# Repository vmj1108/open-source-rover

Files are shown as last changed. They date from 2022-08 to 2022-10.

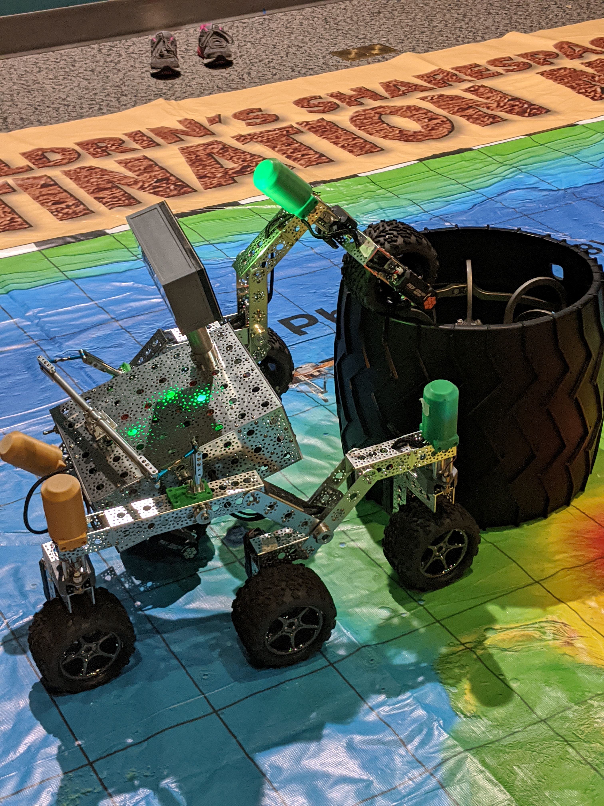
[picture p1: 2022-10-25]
examples/images/roverto/roverto_climbing_wheel.jpg

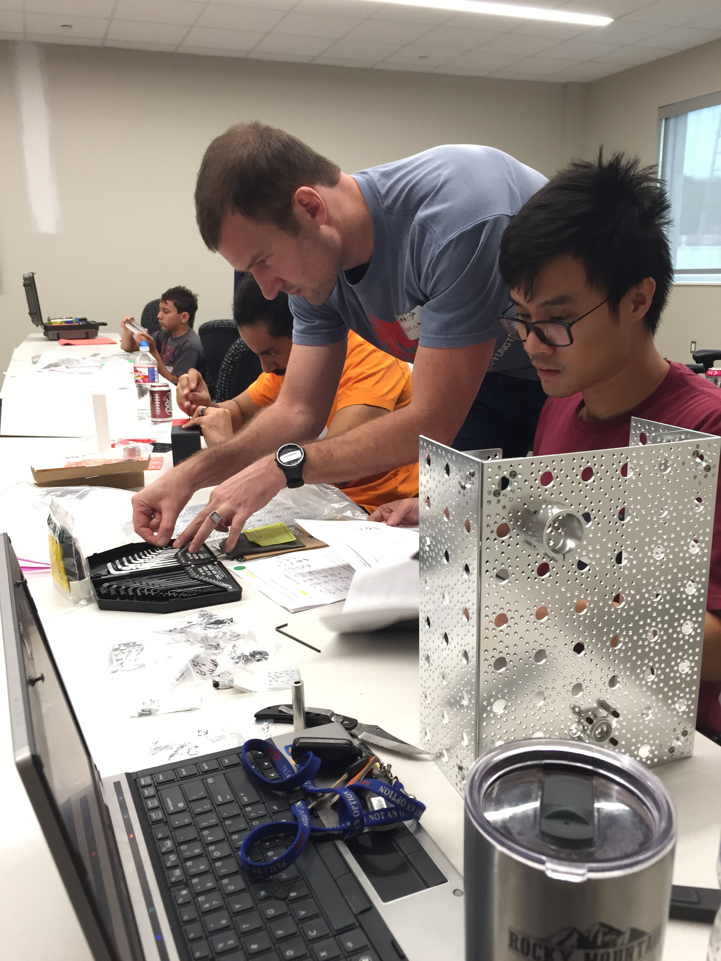
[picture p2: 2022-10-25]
examples/images/AUDACITY/IMG_3927.JPG

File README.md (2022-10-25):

# JPL Open Source Rover Project

The JPL Open Source Rover is an open source, build it yourself, scaled down version of the 6 wheel rover design that JPL uses to explore the surface of Mars. The Open Source Rover is designed almost entirely out of consumer off the shelf (COTS) parts. This project is intended to be a teaching and learning experience for those who want to get involved in mechanical engineering, software, electronics, or robotics.

<table>
 <tr>
  <td align="center" >  </td>
  <td align="center" > <a href="https://github.com/lschooley/open-source-rover-mission-patch">
    </a>
  </td>
 </tr>
 <tr>
  <td align="center" > </td>
 <td align="center" ></td>
 </tr>
</table>

A gallery of some community builds can be found [here](examples/builders_gallery.md).

## About the Project

### Motivation

JPL is always looking to inspire the next generation of scientists, engineers, and roboticists to help us explore and learn about our solar system (and beyond!). We release the plans for this rover as a way to try and give budding enthusiasts a fun robotics project that will help teach them and get them involved in robotics sooner and at a lower cost.

---

### Specifications & Technical Attributes

The specific attributes of the robot you build will depend slightly on the type of electronics and motors you buy for the system.  The numbers shown below are for the version of the robot that contains exactly the parts that we suggest in our build documents and parts list. Below, you can see which parts could be changed for which spec upgrades.

| Attribute | Value [imperial] | Value [SI] |
| --- |:-----: | :---: |
| Weight | 28 [lbs] | 12.7 [kg] |
| Footprint | 24x14 [in] | 60.96x30.48 [cm] |
| Battery Capacity | 5200 [mAh] | 5200 [mAh] |
| Battery Discharge Rate | 8 [A] | 8 [A] |
| Nominal Current Draw | 1.2 [A] | 1.2 [A] |
| Operating time | 5 [hrs] (continual use)  | 5 [hrs] (continual use)|
| Approximate Max speed | 68.8 [in/s] | 1.75 [m/s] |
| Maximum 90 deg vertical scale | 12 [in] | 30.48 [cm] |
| Maximum height differential between sides | 14 [in] | 35.56 [cm] |
| Communication (in this guide) | Bluetooth app (Android only) and Xbox Controller| |
| Cost (*) | ~ $2,500 | |

Again, the above statistics depend on which components you select when buying parts. One potential change is for the motors; you can, for example, select higher RPM motors (to drive your rover faster) at the sacrifice of max stall torque, which would potentially limit your rover's ability to climb. A selection of motors that would integrate easily with the rest of the suggested rover design can be found at [GoBilda](https://www.gobilda.com/5202-series-yellow-jacket-planetary-gear-motors/).

(*) Other open-source, cheaper alternatives exist but are slower, less strong, and are more fragile. See [Additional Projects](#additional-projects).

---

### Communication

In addition to this repository which holds all the documentation for this project, there are two additional websites tied to this project. One is a [landing site](https://opensourcerover.jpl.nasa.gov) which holds general information and an overview of the rover and how it works:

We have a few ways to connect with the team and community of Open Source Rover builders:

* [Slack](https://join.slack.com/t/opensourcerover/shared_invite/zt-mfe0viua-FhcYsNb3S9vUra99uF3IBw) (Preferred method)
* [TapaTalk - JPL Open Source Rover](https://www.tapatalk.com/groups/jpl_opensource_rover/) (Tapatalk is being monitored less since the addition of Slack, that's the easiest way to reach many of us now)
* We also use [Github Discussions](https://github.com/nasa-jpl/open-source-rover/discussions)

****Note: JPL and Caltech have no official affiliation with this forum; it is run by individuals of the general public.**** On these you can ask questions if you need help or clarification on any aspects of the project.  Additionally, you can post and promote any modifications or addons that you have created on this project. We highly encourage additions and modifications to be posted so that this project and community can grow.

---

### Features

This rover is designed to function similarly to the 6 wheel rover designs on Mars and employs a few of the major driving mechanics that the mars rovers use to traverse rocky surfaces:

* **Rocker-Bogie:** The Rocker-Bogie suspension system allows all 6 wheels to continually be in contact with the ground while climbing over obstacles
* **Differential Pivot:** Allows weight to be mechanically offloaded from one side of the rover to the other while climbing
* **6-Wheel Ackerman Steering:** Driving and steering/turning mechanism that governs where the wheels point and how fast each of them will move.

We chose a Raspberry Pi to be the "brain" of this rover for its versatility, accessibility, simplicity, and ability to add and upgrade your own modifications. Any method with which you can communicate with a Raspberry Pi (bluetooth, WiFi, USB devices, etc) can be interfaced into the control system of the robot.

Rover communication

In addition, here are the open communication ports and hardware on the Raspberry Pi:

* 4 USB ports (3 if using Xbox controller)
* RPi Camera port
* 1 I2C Bus (0 if using LED Matrix screen)
* 2 SPI Bus (1 if using LED Matrix screen)
* 3.5mm Audio Jack
* 13 GPIO pins (6 if using LED Matrix screen)

Using the above ports, you could theoretically drive the rover autonomously from the camera, via a USB dongle attached to anything (your own video game controller, a USB microphone, or many others... be creative!), or through any interface using the Pi's GPIO ports (distance sensors, accelerometers, and much more).  We've only given you two simple ways to control the rover to start... we want you to come up with even more!

For the power system of the rover, there is also ample spare power which can be used for your own addons and upgrades.  See the [Electrical subsystem documentation](electrical/) for more specific details.

---

### Maintenance Status

As an open-source hardware project, the rover is continuously improving. Please check ongoing [projects](https://github.com/nasa-jpl/open-source-rover/projects), [issues](https://github.com/nasa-jpl/open-source-rover/issues), [pull requests](https://github.com/nasa-jpl/open-source-rover/projects), and the forum (see below) to see if any big changes are expected soon.

### Online 3D Model


<p>

</p>

There is also an [Onshape model of the Open Source Rover](https://cad.onshape.com/documents/5c358484057fc4c01d5e5803/w/bdf583acdf29d75695be5fbc/e/e3eb7193ecdec5b0a710978b). The model includes the state of the rover at each individual step throughout our build instructions! Therefore, you should be able to reference the online 3D model in addition to the photos in the build instructions as you are building to ensure your build is going well. NOTE: The most updated model and single source of truth are the SolidWorks assemblies and the OnShape model may be out of date.

---

### Rover Mission Patch



Thank you to Lauren Schooley for creating a mission patch for the project. The patch is free for use as a team patch, for stickers, or decorating your rover. The design is released under the Creative Commons Attribution-NoDerivatives public license. A variety of file formats is available.

* [Mission Patch](https://github.com/lschooley/open-source-rover-mission-patch)

---

### Skills Necessary

This project has elements in mechanical assembly/fabrication, uses a host of electrical components, and has software that will run it all. In order to complete this project, you will need to have some experience in the following:

* **Fabrication/Machining:** Although most the parts are COTS there are a few modifications necessary to adapt them to the project. These modifications will be in the form of
  * Metal cutting using band saw/dremel
  * Drilling using drill press/hand drill
  * Filing and sanding for part cleanup
  * General Fabrication/Machining Safety
* **Electronics:** This project uses components like motors, motor controllers, and batteries. It will be important to have experience with the following electrical processes.
  * Soldering
  * Electrical debugging
  * Wiring
  * Electrical Safety
* **Software:** The rover's brain is a Raspberry Pi. All code can be found in the [osr-rover-code](https://github.com/nasa-jpl/osr-rover-code) repository along with step-by-step instructions to set it up. Basic familiarity with Linux, ROS, and Python will be helpful though.

Most of the above are skills that you can learn and pick up fairly quickly from watching videos and doing research on the internet, and throughout the project we try to give supplemental information on some of these as well.  See the build documents for more information.

---

### Tools Necessary

This project assumes you have some standard tools to help assemble the project. If you do not have any of the optional tools, we provide examples of online services that you can use to have the parts fabricated and sent to you.

#### Mandatory tools

* SAE Hex Key set
* SAE Wrench set
* Pliers
* Wire Snips
* Wire Strippers
* Solder Iron
* Solder
* Digital Multimeter
* Hand Drill or Drill Press
* Dremel, Band saw, or hand saw
* Items for operating a Raspberry Pi (Keyboard, mouse, monitor, 5V micro USB power adapter)
* Wire strippers, e.g. [these](https://www.amazon.com/dp/B07DWVSR41/?coliid=ISMG8XMBILGFK&colid=1IM7RHK25RIBB&psc=0&ref_=lv_vv_lig_dp_it)

#### Optional Tools

* 3D printer
* Laser Cutter
* Power Supply (to test without using battery)

---

### Expected time commitment

In our experience, this project takes no less than 200 person-hours to build, and depending on the familiarity and skill level of those involved could be significantly more. Experienced builders may be able to build this project in this amount of time.  However, this project is generally meant to be a teaching and learning tool.  Throughout the documentation, we try to give supplemental information for those who might be new to this kind of project.

# Disclaimer

**Reference herein to any specific commercial product, process, or service by trade name, trademark, manufacturer, or otherwise, does not constitute or imply its endorsement by the United States Government or the Jet Propulsion Laboratory, California Institute of Technology. Government sponsorship acknowledged.**

**By downloading, cloning, or otherwise using the contents of this repository, you agree to the terms specified in the attached [DISCLAIMER.txt file](/DISCLAIMER.txt).**

## Getting Started

---

### Ordering parts

#### Parts Lists

The [Master Parts List](parts_list/master_parts_list_raw.csv) contains all the parts necessary to build the entirety of the robot as it is listed in our documentation. We recognize that you may want to change, add, and redesign some sections, so each of the individual build sections also contain a parts list for that corresponding section of the project. *Note that these individual parts list recommend buying quantities necessary **only for that section**.  Be sure to assess the quantities you need for common items (particularly screws, nuts, bolts, and other common hardware) if you are changing subassemblies.*

##### Cart Share

In order to help this ordering process we have compiled a few links of a large number of these together already, if you wish to build exactly what is in our build documentation. Note that some of these parts might not be available or outdated. Please check the master parts list for the most up-to-date list of items.

|[McMaster](https://www.mcmaster.com/order/rcvRtedOrd.aspx?ordid=5887891246&lnktyp=txt)|[Amazon](https://www.amazon.com/gp/registry/wishlist/3ELV1FY8J7ZYP/ref=cm_sw_em_r_z_g__wb)|[Pololu](https://www.pololu.com/wishlist/1J10953)|[Adafruit](https://www.adafruit.com/wishlists/460400)|
|---|---|---|---|

**Electronics**

The easiest way to buy the electronics parts is to use the links (to e.g. Digikey) on the Kitspace pages:

* [control-board](https://kitspace.org/boards/github.com/nasa-jpl/open-source-rover/open-source-rover-control-board/)
* [arduino-shield](https://kitspace.org/boards/github.com/nasa-jpl/open-source-rover/open-source-rover-shield/)

Another way to order from Digikey is to upload the [Digikey Bill of Materials](bill_of_materials/Digikey_BOM.csv) at [Digikey.com](https://www.digikey.com/).

#### 3D printing and Laser cutting

In addition to ordering all of the parts on the parts list, we recommend that some pieces be 3D printed and laser cut. If you do not have access to a 3D printer or laser cutter, we've added some online services as examples for where you can get those manufactured and shipped to you. You'll find instructions on this in the [Body Build Doc](mechanical/body_assembly/README.md),  [Corner Steering Build Doc](mechanical/corner_steering/README.md), and [Head Assembly Build Doc](mechanical/head_assembly/README.md).

#### Printed Circuit Boards (PCBs)

The main electrical system of this rover relies on a custom printed circuit board (PCB) that handles the routing between the majority of the electrical components. This board greatly simplifies the build process and eliminates the need for you to route all the wires yourself. You can find the PCB board files at [PCB Files](https://github.com/nasa-jpl/open-source-rover/tree/master/electrical/pcb/).

The easiest way to order the PCBs is through the links (to e.g JLCPCB) on the Kitspace pages:

* [control-board](https://kitspace.org/boards/github.com/nasa-jpl/open-source-rover/open-source-rover-control-board/)
* [arduino-shield](https://kitspace.org/boards/github.com/nasa-jpl/open-source-rover/open-source-rover-shield/)

You can also download the "Gerber" files there (a typical file format for PCBs) and upload them to any other PCB service that doesn't have a direct link on Kitspace.

---

### Rover Build Roadmap

Rover build roadmap

Above is an example roadmap of how you can build the rover and which parts of the build are dependent on the other sections. It is broken down into 5 stages:

* **Stage 1:** Start getting all the parts!  

* **Stage 2:** Once you have all the parts, everything in stage 2 can be completed in parallel. It is *highly* recommended to start on the electrical testing of components outside the robot before doing any electrical work inside the completed robot body. You can also work on the software at any stage between here and the end.

* **Stage 3:** During stage 3, the mechanical subassemblies should all be assembled and start to be integrated together.  There should be some amount of testing done on the electrical system, as well as some progress on the software.

* **Stage 4:** The rover is mechanically built and all subassemblies integrated together.  During stage 4, you begin the integration of the electrical components and the various power and data wires that run throughout the rover.

* **Stage 5:** Once the electronics are all powered and communicating, you need to test and calibrate all the motors in the system.

* **Stage 6:** After everything has been tested and calibrated and the software is up and running, the robot will be fully functioning and built!

* **Stage 7:** Add your own upgrades! We chose Raspberry Pi as the brain of the project so that it should be easy to add, change, and upgrade to build exciting things on top of this already cool robot.  Some upgrade ideas to get you brainstorming: sonar for collision detection, IMU for orientation / closed-loop driving / obstacle mapping, camera for object identification and tracking, sensor packages (temperature, pressure, humidity), solar panels, or even a robotic arm!

---

## Getting help / joining the community

If you have any questions or run into problems during your build, please search for answers and/or reach out on [Github Discussions](https://github.com/nasa-jpl/open-source-rover/discussions). Please also take a look at the list of [open issues](https://github.com/nasa-jpl/open-source-rover/issues). If you think there is an error or a part is missing, please create a new issue.

---

## Project Team

These were the original creators of this project. Now, this open-source repository is run by volunteer maintainers from the community.

### Project Lead

Michael (Mik) Cox

### Development Team

Eric Junkins and Olivia Lofaro

### Special Thanks To

Magdy Bareh, Michelle Viotti, Tom Soderstrom, Dave Gallagher, Jim Rinaldi, Molly Bittner, Christine Fuller, Billy Allen, and Charles Dandino

## Additional Projects

We recognize that there might be a some individuals, hobbyists, and groups that might be hesitant or unable to build the Open Source Rover due to skills/tools necessary, or budgetary constraints. Here are some other open-source alternatives.

* [Sawppy Rover](https://hackaday.io/project/158208-sawppy-the-rover)
* [ESA ExoMy](https://github.com/esa-prl/ExoMy)

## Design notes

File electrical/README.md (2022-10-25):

# JPL Open Source Rover Project

The JPL Open Source Rover is an open source, build it yourself, scaled down version of the 6 wheel rover design that JPL uses to explore the surface of Mars. The Open Source Rover is designed almost entirely out of consumer off the shelf (COTS) parts. This project is intended to be a teaching and learning experience for those who want to get involved in mechanical engineering, software, electronics, or robotics.

## Overview

This is a feature testing branch for an electronics rework, for moving towards a monolithic "motherboard" approach for to reduce wiring complexity and lower the barrier of entry for the project, as well as make the system more robust.

## Disclaimer

This information is not fully tested yet, and is being put here as a development branch incase some want to start working on these parts. It will eventually be added into the main repository once testing has been completed and documentation added. Until then this will be incomplete for information as things will be changing rapidly.

## Board ordering/assembly

If you do wish to purchase these boards/items previous to the final release to help test/document and contribute to the project we would greatly appreciate the help! There is an excel spreadsheet here which has a parts list of all things necessary.

[Master Parts List](../parts_list/master_parts_list_raw.csv)

In here currently are just the gerber files necessary to order the boards in their current revision. Eventually I will upload the libraries/kicad files so everyone can make edits to them, but in order to just get information up here it will just be the gerbers at first. They can be found in [the PCB folder](/electrical/pcb/).

To order these boards we suggest that you order from [JLCPCB](https://jlcpcb.com/), this PCB fabrication company is quite inexpensive for this board size and has good turnaround time. Upload the .zip files individually and make sure the following settings are set:

* Layers - 2
* Dimension - 53 x 69 mm (arduino shield) & 175 x 154 mm (roboclaw breakout)
* PCB Qty - 10
* PCB Thickness - 1.6 mm
* PCB Color - Whatever color you want
* Surface Finish - HASL
* Copper Weight - 1oz
* Gold Fingers - No
* Panel by JLPCB - No
* Flying Probe Test - Fully Tested
* Castellated Holes - No
* Different Design - 1

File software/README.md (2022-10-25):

# Software Subsystem

This section of the repository details how to get all the software that is necessary for driving the rover up and running. See the project's main [roadmap](https://github.com/nasa-jpl/open-source-rover/blob/master/images/roadmap.png) for information on when you should be creating your software and how to integrate it with the rest of the rover.

6 Wheel Rover

# Disclaimer

**By downloading, cloning, or otherwise using the contents of this repository, you agree to the terms specified in the attached [DISCLAIMER.txt file](/DISCLAIMER.txt).**

# Getting Started with the Software Build

The [Rover Code repo](https://github.com/nasa-jpl/osr-rover-code)'s README files will walk you through all necessary steps for getting the rover software up and running on the Raspberry Pi. These steps can be completed at any point during the project, all the way up to when all the electronics and mechanical parts are completed and you are ready to start driving and controlling the robot.

Note the [Software Controls.pdf](Software%20Controls.pdf) doc is out-of-date and should be ignored for now.

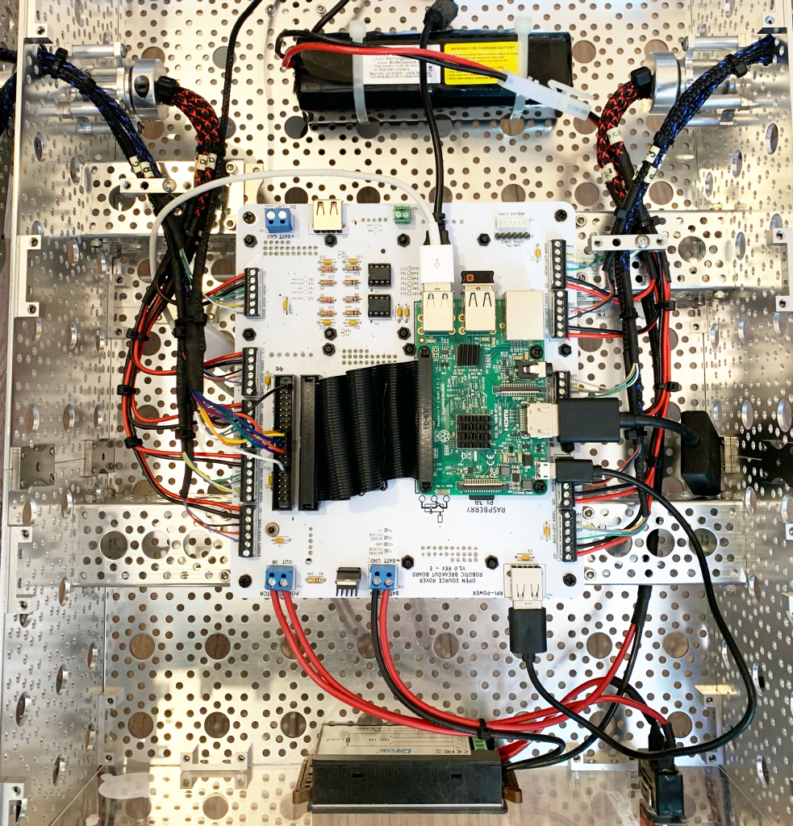
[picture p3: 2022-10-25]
examples/images/sinuhe/electrical2.png

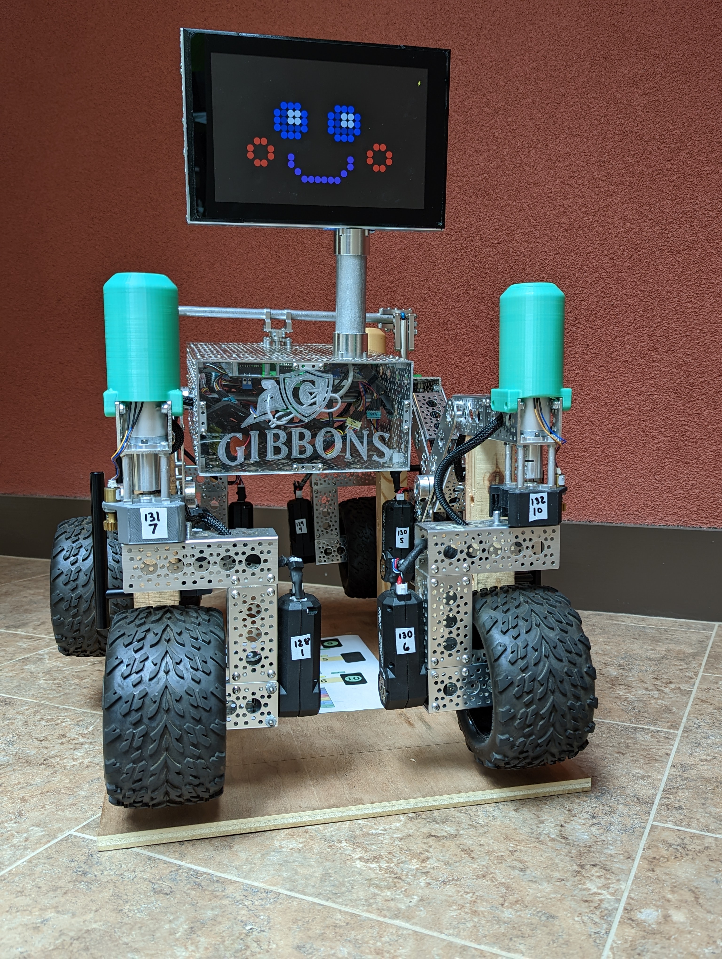
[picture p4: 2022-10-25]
examples/images/roverto/roverto.jpg

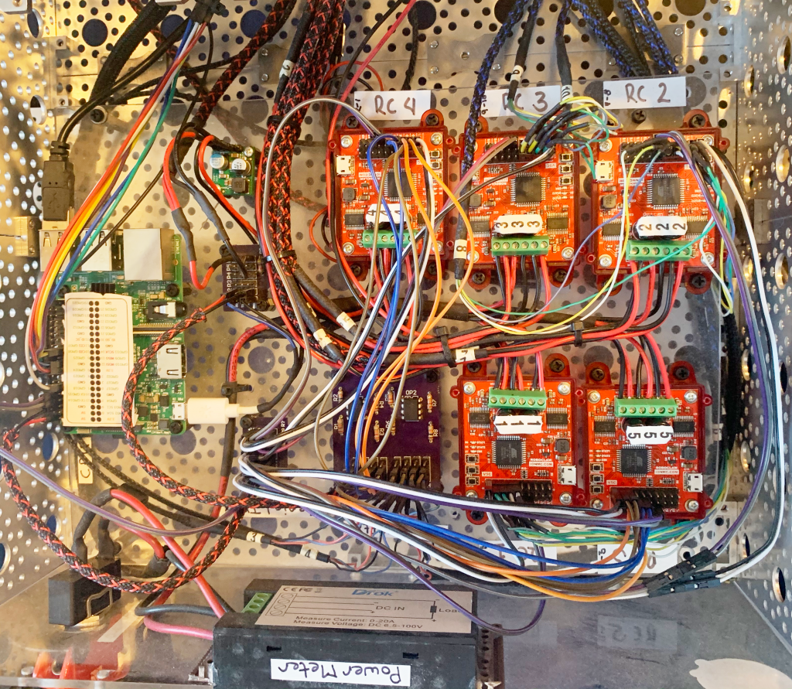
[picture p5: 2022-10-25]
examples/images/sinuhe/electrical1.png

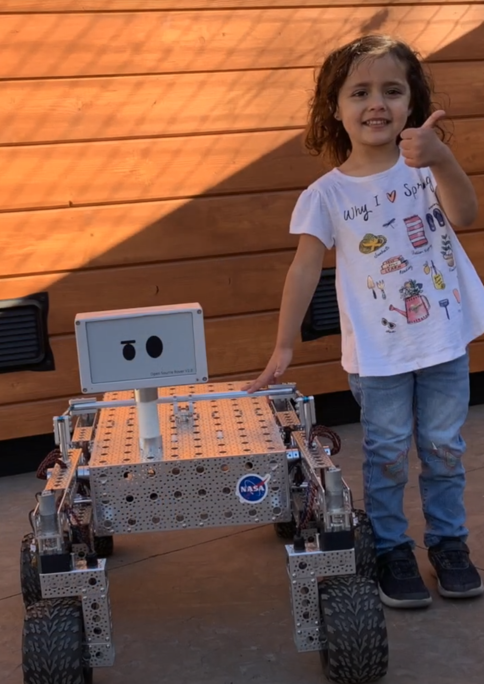
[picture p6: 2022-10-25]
examples/images/sinuhe/sinuhe1.png

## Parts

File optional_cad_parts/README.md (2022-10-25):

# Optional CAD parts

These are parts that have been designed as addons and additional parts for the open source rover. Some of these will be eventually included into build doc instructions.

These 3D printed parts were designed to be printed in PLA on the Raise 3D printer, and as such the tolerances/dimensions are designed to print well on that specific printer. Your individual printer may very on how it prints these based on individual settings, however they should be designed such that any modern conventional printer can complete the parts.

## Folder Structure

Each of the folders in here contains a different file type, which is dependant on the manufacturing process used to create the part. The folders are as follows:

* DXF - 2 dimensional part files for items to be laser cut out of acrylic
* STL - 3 dimensional part files for items to be 3D printed.
* SolidWorks - Native solidworks CAD files used to create the parts
* STEP - Generic CAD files to open in programs not solidworks

## Part Overview

Every part has a SolidWorks and STEP file associated with it, in case you wish to make modifications. In general most parts are designed to use heat set inserts from McMaster Carr, which allow you to add metal threads to 3D printed parts.

[https://www.mcmaster.com/heat-set-inserts](https://www.mcmaster.com/heat-set-inserts)

I'll give a brief description of the each of the parts as well as list any items that are necessary for that part.

### 3D printed parts

* Battery holder - Clamps for the batteries, to be held against the side walls of the body/chassis.
  * Requires - PCB update probably to free up some space inside your rover.
  * Uses #6 - heat set inserts (short)
* Bearing block - Blocks to bolt onto the back of the Servocity bearing pillow blocks. I use these instead of hex nuts on the back of the pillow blocks in the Rocker-bogie
  * Uses #6 - heat set inserts (short)
* cap_base - Motor mount cover for pololu corner steering motors (to be updated to servo city corner steering motor soon)
  * Uses #6 - heat set inserts (short)
* cap_with_jpl - Motor cap with JPL embossed on the side
* cap_without_jpl - Motor caps that are pure cylinder
* div-piv mounting block - Mounting block for the 0.5 in clamping hub to attach the differential pivot on the rocker-bogie arms. This piece will help level out the body of the rover instead of it being slanted
  * Uses #6 - heat set inserts (short)
* head base - Redesign of the LED screen head mount, printed in one single large piece
  * Uses M2.5 - heat set inserts (short)
  * Requires - PCB Update to run Arduino in LED head
  * Requires - Arduino plate (laser cut file)
* Sub-d female bottom - Sub-D mounting piece to have a connector between the rover body and head, at the PVC clamping hub at the neck. This allows you to remove the LED screen.
  * Uses #6 - heat set inserts (short)
  * Uses #4 - heat set inserts (short)
  * Requires - sub-d connector, female [https://www.digikey.com/product-detail/en/assmann-wsw-components/A-DF-09-LL-Z/AE11063-ND/5051922](https://www.digikey.com/product-detail/en/assmann-wsw-components/A-DF-09-LL-Z/AE11063-ND/5051922)
  * Requires - Sub-d male top (3D printed piece)
  * Requires - PCB update to reduce number of cables ran to LED screen
* Sub-d male top - Sub-D mounting piece to have a connector between the rover body and head, at the PVC clamping hub at the neck. This allows you to remove the LED screen.
  * Uses #6 - heat set inserts (short)
  * Uses #4 - heat set inserts (short)
  * Requires - [https://www.digikey.com/product-detail/en/assmann-wsw-components/A-DS-09-LL-Z/AE10972-ND/1241781](https://www.digikey.com/product-detail/en/assmann-wsw-components/A-DS-09-LL-Z/AE10972-ND/1241781)
  * Requires - Sub-d female bottom (3D printed piece)
  * Requires - PCB Update to reduce number of cables ran to LED screen
* Turn buckle holder - Replaces the 5 hole aluminum beams and drilling process to mount the differential pivot by giving a 3D printed cap (recommended to use adhesive to attach it though)
  * Uses #4 - heat set inserts
* USB hub 4pos lid - Lid for 4 position powered USB hub for RPi USB to be accessible outside the robot.
  * Uses M1.6 heat set inserts (short)
  * Requires - [https://www.amazon.com/Anker-Ultra-Slim-Portable-Adapter-Notebook/dp/B0192LPK5M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](https://www.amazon.com/Anker-Ultra-Slim-Portable-Adapter-Notebook/dp/B0192LPK5M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)
  * Requires - front panel (laser cut part)
* USB hub 4pos - Base for 4 position powered USB hub for RPi USB to be accessible outside the robot.
  * Uses M1.6 heat set inserts (short)
  * Requires - [https://www.amazon.com/Anker-Ultra-Slim-Portable-Adapter-Notebook/dp/B0192LPK5M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](https://www.amazon.com/Anker-Ultra-Slim-Portable-Adapter-Notebook/dp/B0192LPK5M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)
  * Requires - front panel (laser cut part)
* USB hub 7pos - Powered USB hub to connect Roboclaws debug micro USB line to outside of robot with one single cable
  * Uses #6 - heat set inserts (short)
  * Requires - [https://www.amazon.com/Anker-7-Port-Adapter-Charging-iPhone/dp/B014ZQ07NE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](https://www.amazon.com/Anker-7-Port-Adapter-Charging-iPhone/dp/B014ZQ07NE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)
  * Requires - back panel (laser cut part)

### Laser cut parts

These were all laser cut out of 1/8 inch acrylic

* Arduino plate - Mounts the Arduino in the Head to the 3D printed head base piece
  * Requires - PCB Update
  * Requires - head base
* Head back panel - Back panel to the head - base part
  * Requires - head base
* Front panel - Front panel for main rover chassis, designed to hold the 4 pos USB hub
  * Requires - USB hub 4 pos
* Back panel - Back panel for main rover chassis, designed to hold the switch, volt meter, 7 pos USB hub, and powerpole connectors for battery charging
  * Requires - USB hub 7 pos

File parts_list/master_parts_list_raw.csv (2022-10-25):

Part Name | Project Ref Code | Model/Config | Site | Link | Sold in Packs of | Total Used in Project | Quantity to Buy | Price Each | Price Total | Used in Sections
#6-32 x 1/4 Button Head Screw | B1 | 92949A144 | McMaster | https://www.mcmaster.com/92949a144 | 100 | 228 | 3 | $3.45 | $10.35 | Body, Corner Steering, Differential Pivot, Mechanical Integration, Wheel Assembly
#6-32 x 3/8 Button Head Screw | B2 | 92949A146 | McMaster | https://www.mcmaster.com/92949A146 | 100 | 72 | 1 | $3.72 | $3.72 | Body, Head Assembly, PCB Assembly, Rocker-Bogie
#6-32 x 1/2 Button Head Screw | B3 | 92949A148 | McMaster | https://www.mcmaster.com/92949A148 | 100 | 8 | 1 | $3.72 | $3.72 | Wheel Assembly
#6-32 x 5/8 Button Head Screw | B4 | 92949A150 | McMaster | https://www.mcmaster.com/92949A150 | 100 | 32 | 1 | $4.07 | $4.07 | Rocker-Bogie
#6-32 x 3/4 Button Head Screw | B5 | 92949A151 | McMaster | https://www.mcmaster.com/92949A151 | 100 | 28 | 1 | $4.41 | $4.41 | Corner Steering, Wheel Assembly
#6-32 x 1.0 Button Head Screw | B6 | 92949A153 | McMaster | https://www.mcmaster.com/92949A153 | 50 | 4 | 1 | $5.42 | $5.42 | Body
#6-32 x 1.25 Button Head Screw | B7 | 92949A160 | McMaster | https://www.mcmaster.com/92949A160 | 50 | 8 | 1 | $6.51 | $6.51 | Differential Pivot
#4-40 x 1/4 Button Head Screw | B8 | 92949A106 | McMaster | https://www.mcmaster.com/92949a106 | 100 | 52 | 1 | $3.02 | $3.02 | Head Assembly, PCB Assembly
#4-40 x 1.25 Button Head Screw | B9 | 92949A118 | McMaster | https://www.mcmaster.com/92949A118 | 100 | 4 | 1 | $7.70 | $7.70 | Differential Pivot
M2.5 x 6mm Screw | B10 | 92095a458 | McMaster | https://www.mcmaster.com/92095a458 | 25 | 16 | 1 | $7.07 | $7.07 | Head Assembly, PCB Assembly
#6-32 Locknuts | B11 | 90631A007 | McMaster | https://www.mcmaster.com/90631A007 | 100 | 72 | 1 | $2.72 | $2.72 | Body, Differential Pivot, Rocker-Bogie
#4-40 Locknuts | B12 | 90631A005 | McMaster | https://www.mcmaster.com/90631A005 | 100 | 4 | 1 | $2.79 | $2.79 | Differential Pivot
#2-56 x 1/4" Screw | B13 | 91255A076 | McMaster | https://www.mcmaster.com/91255a077 | 25 | 8 | 1 | $3.78 | $3.78 | PCB Assembly
M3 x 6mm Screw | B14 | 90751A110 | McMaster | https://www.mcmaster.com/90751a110 | 100 | 6 | 1 | $6.33 | $6.33 | Head Assembly
Red Wire 20AWG | X1 | CN541R-50-ND | Digikey | https://www.digikey.com/products/en?keywords=CN541R-50-ND | 1 | 2 | 2 | $15.59 | $31.18 | Electrical Build
Black Wire 20AWG | X2 | CN538B-50-ND | Digikey | https://www.digikey.com/products/en?keywords=CN538B-50-ND | 1 | 2 | 2 | $12.56 | $25.12 | Electrical Build
White Wire 24AWG | X3 | CN519W-50-ND | Digikey | https://www.digikey.com/products/en?keywords=CN519W-50-ND | 1 | 1 | 1 | $9.16 | $9.16 | Electrical Build
Blue Wire 24AWG | X4 | CN522L-50-ND | Digikey | https://www.digikey.com/products/en?keywords=CN522L-50-ND | 1 | 1 | 1 | $9.16 | $9.16 | Electrical Build
Yellow Wire 24AWG | X5 | CN520Y-50-ND | Digikey | https://www.digikey.com/products/en?keywords=CN520Y-50-ND | 1 | 1 | 1 | $9.16 | $9.16 | Electrical Build
Green Wire 24AWG | X6 | CN524G-50-ND | Digikey | https://www.digikey.com/products/en?keywords=CN524G-50-ND | 1 | 1 | 1 | $9.16 | $9.16 | Electrical Build
Control Board | E1 |  | JLCPCB | https://jlcpcb.com/ | 10 | 1 | 1 | $22.10 | $22.10 | Body, PCB Assembly
Arduino Shield | E2 |  | JLCPCB | https://jlcpcb.com/ | 10 | 1 | 1 | $5.00 | $5.00 | Head Assembly, PCB Assembly
Term block 6p side entry | E3 | ED2744-ND | Digikey | https://www.digikey.com/product-detail/en/OSTTE060104/ED2744-ND/2351820/?itemSeq=281160152 | 1 | 12 | 12 | $1.24 | $14.88 | PCB Assembly
Term block 6P top entry | E4 | ED2627-ND | Digikey | https://www.digikey.com/product-detail/en/OSTTF060161/ED2627-ND/614576/?itemSeq=281160153 | 1 | 7 | 7 | $1.74 | $12.18 | PCB Assembly
Connector Header socket 20P 2x10 | E5 | S6106-ND | Digikey | https://www.digikey.com/product-detail/en/PPPC102LFBN-RC/S6106-ND/807245/?itemSeq=281160175 | 1 | 6 | 6 | $1.26 | $7.56 | PCB Assembly
Connector Header socket 5P 5x1 | E6 | S7038-ND | Digikey | https://www.digikey.com/product-detail/en/PPPC051LFBN-RC/S7038-ND/810177/?itemSeq=281160150 | 1 | 8 | 8 | $0.49 | $3.92 | PCB Assembly
Resistors 4.7K 1/4 Watt | E7 | CF14JT4K70CT-ND | Digikey | https://www.digikey.com/products/en?keywords=CF14JT4K70CT-ND | 10 | 10 | 1 | $0.04 | $0.04 | PCB Assembly
Resistors 10K 1/4 Watt | E8 | CF14JT10K0CT-ND | Digikey | https://www.digikey.com/product-detail/en/stackpole-electronics-inc/CF14JT10K0/CF14JT10K0CT-ND/1830374 | 10 | 10 | 1 | $0.04 | $0.04 | PCB Assembly
Resistors 22K 1/4 Watt | E9 | CF14JT22K0CT-ND | Digikey | https://www.digikey.com/product-detail/en/stackpole-electronics-inc/CF14JT22K0/CF14JT22K0CT-ND/1830383 | 10 | 10 | 1 | $0.04 | $0.04 | PCB Assembly
Resistors 10K 1/2 Watt | E10 | S10KHCT-ND | Digikey | https://www.digikey.com/product-detail/en/stackpole-electronics-inc/CFM12JT10K0/S10KHCT-ND/2617547 | 10 | 10 | 1 | $0.06 | $0.06 | PCB Assembly
Capacitor 100nF | E11 | 399-4454-1-ND | Digikey | https://www.digikey.com/product-detail/en/C410C104M5U5TA7200/399-4454-1-ND/818311/?itemSeq=283708856 | 1 | 30 | 30 | $0.18 | $5.40 | PCB Assembly
Term block 2P side entry (5.08mm) | E12 | ED2580-ND | Digikey | https://www.digikey.com/products/en?keywords=ED2580-ND | 1 | 4 | 4 | $0.75 | $3.00 | PCB Assembly
Connector Header pin 40P 2x20 | E13 | S9175-ND | Digikey | https://www.digikey.com/product-detail/en/SBH11-PBPC-D20-ST-BK/S9175-ND/1990068/?itemSeq=281160147 | 1 | 3 | 3 | $0.73 | $2.19 | PCB Assembly
Connector Header pin 6P 6x1 | E14 | 455-1708-ND | Digikey | https://www.digikey.com/product-detail/en/jst-sales-america-inc/B6B-PH-K-S-LF-SN/455-1708-ND/926615 | 1 | 3 | 3 | $0.66 | $1.98 | PCB Assembly
0.1"+A72 Pitch Pin Header (40 pins) | E15 | S1011EC-40-ND | Digikey | https://www.digikey.com/products/en?keywords=S1011EC-40-ND | 1 | 5 | 5 | $0.59 | $2.95 | PCB Assembly
10A Fuse | E16 | 507-1916-ND | Digikey | https://www.digikey.com/products/en?keywords=507-1916-ND | 1 | 3 | 3 | $0.35 | $1.05 | PCB Assembly
Power Diode | E17 | 497-2738-5-ND | Digikey | https://www.digikey.com/product-detail/en/STPS10L25D/497-2738-5-ND/603763/?itemSeq=281160145 | 1 | 1 | 1 | $1.55 | $1.55 | PCB Assembly
Term block 2P side entry | E18 | 277-1721-ND | Digikey | https://www.digikey.com/product-detail/en/phoenix-contact/1984617/277-1721-ND/950849 | 1 | 3 | 3 | $0.48 | $1.44 | PCB Assembly
Connector Header pin 16P 2x8 | E19 | ED10523-ND | Digikey | https://www.digikey.com/product-detail/en/302-S161/ED10523-ND/2794234/?itemSeq=281160135 | 1 | 2 | 2 | $0.42 | $0.84 | PCB Assembly
Roboclaw Motor Driver | E20 | 2x7A | Pololu | https://www.pololu.com/product/3284 | 1 | 5 | 5 | $69.95 | $349.75 | PCB Assembly
Raspberry pi 3 model b | E21 | B | Amazon | https://www.amazon.com/Raspberry-Model-1-2GHz-64-bit-quad-core/dp/B01CD5VC92?s=electronics | 1 | 1 | 1 | $34.99 | $34.99 | PCB Assembly
5V Buck Boost Regulator | E22 | D24V50F5 | Pololu | https://www.pololu.com/product/2851 | 1 | 1 | 1 | $14.95 | $14.95 | PCB Assembly
12V Regulator | E23 | D24V22F12 | Pololu | https://www.pololu.com/product/2855 | 1 | 1 | 1 | $9.95 | $9.95 | PCB Assembly
Arduino Uno | E24 | 1050-1024-ND | Digikey | https://www.digikey.com/product-detail/en/A000066/1050-1024-ND/2784006/?itemSeq=283429187 | 1 | 1 | 1 | $23.80 | $23.80 | Head Assembly, PCB Assembly
Op Amp LM 358P | E25 | 296-1395-5-ND | Digikey | https://www.digikey.com/products/en?keywords=296-1395-5-ND | 1 | 4 | 4 | $0.37 | $1.48 | PCB Assembly
Rectangular 6P (1x6) Jumper Cable | E26 | 455-3156-ND | Digikey | https://www.digikey.com/product-detail/en/jst-sales-america-inc/A06KR06KR26E305B/455-3156-ND/6194811 | 1 | 1 | 1 | $1.55 | $1.55 | Electrical Build, PCB Assembly
USB A to USB Micro Cable (Data) | E27 | 380-1430-ND | Digikey | https://www.digikey.com/product-detail/en/stewart-connector/SC-2AMK001F/380-1430-ND/8544576 | 1 | 5 | 5 | $2.46 | $12.30 | PCB Assembly
USB A to USB Micro Cable Right Angle | E28 |  | Amazon | https://www.amazon.com/gp/product/B00S8GU03A/ref=crt_ewc_img_dp_2?ie=UTF8&psc=1&smid=A1AMUYYA3CT6HJ | 1 | 1 | 1 | $7.99 | $7.99 | Electrical Build, PCB Assembly
Rectangular 40P (2x20) Ribbon Cable | E29 | 1988 | Adafruit | https://www.adafruit.com/product/1988 | 1 | 1 | 1 | $2.95 | $2.95 | Electrical Build, PCB Assembly
Rectangular 16P (2x8) Ribbon Cable | E30 | H3CCH-1606G-ND | Digikey | https://www.digikey.com/product-detail/en/H3CCH-1606G/H3CCH-1606G-ND/1218559/?itemSeq=281160137 | 1 | 1 | 1 | $1.40 | $1.40 | Electrical Build
4 Position USB Hub | E31 |  | Amazon | https://www.amazon.com/Anker-Ultra-Slim-Portable-Adapter-Notebook/dp/B0192LPK5M | 1 | 1 | 1 | $17.99 | $17.99
7 Position USB Hub | E32 |  | Amazon | https://www.amazon.com/Anker-7-Port-Adapter-Charging-iPhone/dp/B014ZQ07NE | 1 | 1 | 1 | $32.99 | $32.99
DIP IC socket 8P | E33 | AE9986-ND | Digikey | https://www.digikey.com/product-detail/en/A+08-LC-TT/AE9986-ND/821740/?itemSeq=281160151 | 1 | 3 | 3 | $0.17 | $0.51 | PCB Assembly
USB A Connector | E34 |  | Digikey | https://www.digikey.com/product-detail/en/USB-A1HSW6/ED2989-ND/2677750/?itemSeq=283940458 | 1 | 2 | 2 | $0.50 | $1.00 | PCB Assembly
Tamiya Connectors | E35 | E19 | Amazon | https://www.amazon.com/Tamiya-Male-Female-150mm-Venom/dp/B000HKEVH6 | 1 | 1 | 1 | $5.57 | $5.57 | Electrical Build, PCB Assembly
Battery | E36 | Standard Tamiya Connectors | BatterySpace | https://www.batteryspace.com/li-ion-battery-14-8v-5-2ah-77wh-8a-rate-for-diving-light---un-38-3-passed.aspx | 1 | 1 | 1 | $86.95 | $86.95 | Electrical Build, PCB Assembly
LED Array | E37 |  | Adafruit | https://www.adafruit.com/product/420 | 1 | 1 | 1 | $24.95 | $24.95 | Head Assembly, PCB Assembly
Battery Volt Meter | E38 |  | Amazon | https://www.amazon.com/DROK-Multimeter-6-5-100V-Backlight-Measuring/dp/B017FSED9I | 1 | 1 | 1 | $13.24 | $13.24 | Body
Switch | E39 | 432-1282-ND | Digikey | https://www.digikey.com/product-detail/en/bulgin/C3900BA/1091-1026-ND/2747857 | 1 | 1 | 1 | $4.49 | $4.49 | Body
3 pin Micro Connectors | E40 | CA-MIC3-W3-NC-1 | US Digital | https://www.usdigital.com/products/cables-connectors/cables/3-pin/CA-MIC3-W3-NC | 1 | 4 | 4 | $6.80 | $27.20 | Electrical Build
Battery Charger | E41 | Standard Tamiya Connectors | BatterySpace | https://www.batteryspace.com/smart-charger-3-0a-for-14-8v-li-ion-polymer-battery-pack.aspx | 1 | 1 | 1 | $41.95 | $41.95 | Electrical Build
Wire Braid | E42 | 25Ft 0.1875 Diameter | Amazon | https://www.amazon.com/16-Wind-Side-Entry-Sleeving/dp/B06XRKMB7N?s=gateway | 1 | 1 | 1 | $15.00 | $15.00 | Electrical Build
SD Card | E43 | 8Gb | Amazon | https://www.amazon.com/SanDisk-Ultra-Micro-Adapter-SDSQUNC-016G-GN6MA/dp/B010Q57SEE | 1 | 1 | 1 | $9.98 | $9.98
Heat Shrink Tubing | E44 | 532 pc | Amazon | https://www.amazon.com/Shrink-Tubing-Black-532pcs-innhom/dp/B075WR9FVL | 1 | 1 | 1 | $7.99 | $7.99 | Electrical Build
Gear Motor (Corner Motor) | E46 | 45 RPM HD Premium Planetary Gear Motor, NO relative encoder | ServoCity | https://www.servocity.com/45-rpm-hd-premium-planetary-gear-motor | 1 | 4 | 4 | $39.99 | $159.96 | Corner Steering
Absolute Encoder | E47 | 1/8 inch, 10 Bit Analog, Sleeve Bushing (N) | US Digital | https://www.usdigital.com/products/encoders/absolute/rotary/shaft/MA3 | 1 | 4 | 4 | $55.50 | $222.00 | Corner Steering
USB to TTL Serial Adapter | E48 |  | Amazon | https://www.amazon.com/JBtek-WINDOWS-Supported-Raspberry-Programming/dp/B00QT7LQ88?s=gateway | 1 | 1 | 1 | $6.99 | $6.99 | Electrical Build
1.5" U Channel | S1 | 585440 | ServoCity | https://www.servocity.com/1-50-channel | 1 | 2 | 2 | $2.99 | $5.98 | Mechanical Integration
0.25" Pillow Bearing Block | S10 | 535110 | ServoCity | https://www.servocity.com/0-250-1-4-bore-flat-bearing-mount | 1 | 8 | 8 | $5.99 | $47.92 | Corner Steering
0.5" Pillow Block | S11 | 535118 | ServoCity | https://www.servocity.com/0-500-1-2-bore-flat-bearing-mount | 1 | 6 | 6 | $6.99 | $41.94 | Body
0.25" Face Tapped Clamping Hub | S12 | 545588 | ServoCity | https://www.servocity.com/770-clamping-hubs#348=95 | 1 | 4 | 4 | $5.99 | $23.96 | Wheel Assembly
0.5" Face Tapped Clamping Hub | S13 | 545600 | ServoCity | https://www.servocity.com/770-clamping-hubs#348=107 | 1 | 3 | 3 | $5.99 | $17.97 | Differential Pivot
4mm Face Tapped Clamp Hub | S14 | 545608 | ServoCity | https://www.servocity.com/770-clamping-hubs#348=96 | 1 | 6 | 6 | $5.99 | $35.94 | Wheel Assembly
Stainless Steel D-Shaft (1/4in x 1.75in) | S15 | 634070 | ServoCity | https://www.servocity.com/0-250-1-4-x-1-75-1-3-4-stainless-steel-d-shafting/ | 1 | 4 | 4 | $1.59 | $6.36 | Corner Steering
0.5 x 3Ft Aluminum Rod | S16 | 89965K364 | McMaster | https://www.mcmaster.com/89965K364 | 1 | 1 | 1 | $25.74 | $25.74 | Differential Pivot
Dual Side mount A | S17 | 585470 | ServoCity | https://www.servocity.com/90-dual-side-mount | 2 | 16 | 8 | $5.99 | $47.92 | Body
0.5" x 4" aluminum tube | S18 | 635254 | ServoCity | https://www.servocity.com/0-500-1-2-aluminum-tubing#371=455 | 1 | 5 | 5 | $2.19 | $10.95 | Differential Pivot
0.5" x 2" aluminum tube | S19 | 635252 | ServoCity | https://www.servocity.com/0-500-1-2-aluminum-tubing#371=246 | 1 | 1 | 1 | $1.59 | $1.59 | Mechanical Integration
3" Channel | S2 | 585442 | ServoCity | https://www.servocity.com/3-0-channel | 1 | 18 | 18 | $3.99 | $71.82 | Corner Steering, Rocker-Bogie, Wheel Assembly
.5"D Bore Bottom Tapped Clamping Mount | S20 | 585546 | ServoCity | https://www.servocity.com/1-2-bore-bottom-tapped-clamping-mount | 1 | 2 | 2 | $5.99 | $11.98 | Differential Pivot
5 Hole Aluminum Beam | S21 | 585404 | ServoCity | https://www.servocity.com/1-54-aluminum-beam | 2 | 8 | 4 | $2.39 | $9.56 | Differential Pivot
0.5" D Collar Clamp | S22 | 6157K14 | ServoCity | https://www.servocity.com/aluminum-clamp-collars#368=229 | 1 | 12 | 12 | $4.99 | $59.88 | Mechanical Integration
3D Printed PVC Clamping Hub (top) | S24 |  | Makexyz | https://www.makexyz.com/ | 1 | 1 | 1 | $12.90 | $12.90 | Head Assembly
Plain Bore Gear | S26 | RHA32-36-48 | ServoCity | https://www.servocity.com/32-pitch-acetyl-hub-gears-0-1875-face#199=15 | 1 | 4 | 4 | $5.20 | $20.80 | Wheel Assembly
Shaft Mount Pinion Gear (16 Tooth) | S27 | KPL32-32-16 | ServoCity | https://www.servocity.com/0-125-1-8-bore-32p-shaft-mount-pinion-gears-steel#199=100 | 1 | 4 | 4 | $5.99 | $23.96 | Corner Steering
5 Foot PVC | S29 | 48925K93 | McMaster | https://www.mcmaster.com/48925k93 | 1 | 1 | 1 | $5.28 | $5.28 | Head Assembly
3.75" Channel | S3 | 585443 | ServoCity | https://www.servocity.com/3-75-channel | 1 | 4 | 4 | $4.49 | $17.96 | Rocker-Bogie
Wheel | S30 |  | DollarHobbyz | https://www.dollarhobbyz.com/collections/all/products/traxxas-2-talon-tires-gemini-black-chrome-wheels-5374x | 2 | 6 | 3 | $25.27 | $75.81 | Wheel Assembly
3D Printed Encoder Mounts | S31 | /mechanical/corner_steering/3d_printed_parts/Encoder mount.STL | Makexyz | https://www.makexyz.com/ | 1 | 4 | 4 | $12.90 | $51.60 | Corner Steering
RC Turnbuckles | S32 | 06048B | Amazon | https://www.amazon.com/Hobbypark-Aluminum-Turnbuckle-BRONTOSAURUS-Replacement/dp/B01H5PZKMK | 2 | 2 | 1 | $9.25 | $9.25 | Differential Pivot
Loctite Red | S34 |  | Amazon | https://www.amazon.com/Loctite-Threadlocker-Red-0-20-209741/dp/B000FP8EUS | 1 | 1 | 1 | $6.49 | $6.49 | Wheel Assembly
9 x 12 Top Plate | S35 |  | Sculpteo | https://www.sculpteo.com/ | 1 | 1 | 1 | $12.06 | $33.98 | Body
Loctite 2 Part Epoxy | S36 |  | Amazon | https://www.amazon.com/Loctite-Marine-0-85-Fluid-Syringe-1405604/dp/B00KH62K50 | 1 | 1 | 1 | $5.42 | $5.42 | Wheel Assembly
4.5" x 12" Side Plate | S37 | 585004 | Sculpteo | https://www.sculpteo.com/ | 1 | 2 | 2 | $9.64 | $19.28 | Body
0.25" to 6mm Clamping Shaft Coupler | S38 | 625100 | ServoCity | https://www.servocity.com/heavy-duty-clamping-shaft-couplers | 1 | 4 | 4 | $7.99 | $31.96 | Corner Steering
Laser Cut Body Front Panel | S39 |  | Sculpteo | https://www.sculpteo.com/en/lasercutting/ | 1 | 1 | 1 | $7.93 | $7.93 | Body
Laser Cut Body Back Panel | S40 |  | Sculpteo | https://www.sculpteo.com/en/lasercutting/ | 1 | 1 | 1 | $8.42 | $8.42 | Body
3D printed Battery Holder | S41 |  | Makexyz | https://www.makexyz.com/ | 1 | 2 | 2 | $12.50 | $25.00 | Body
Laser Cut Head Back Panel | S42 |  | Sculpteo | https://www.sculpteo.com/en/lasercutting/ | 1 | 1 | 1 | $7.63 | $7.63 | Head Assembly
3D printed Head | S43 |  | Makexyz | https://www.makexyz.com/ | 1 | 1 | 1 | $29.80 | $29.80 | Head Assembly
Laser Cut Arduino Plate | S44 |  | Sculpteo | https://www.sculpteo.com/en/lasercutting/ | 1 | 1 | 1 | $7.76 | $7.76 | Head Assembly
4.5" Channel | S4 | 585444 | ServoCity | https://www.servocity.com/4-50-channel | 1 | 4 | 4 | $4.99 | $19.96 | Wheel Assembly
9" Channel | S5 | 585450 | ServoCity | https://www.servocity.com/9-0-channel | 1 | 2 | 2 | $7.99 | $15.98 | Rocker-Bogie
Channel Connectors | S6 | 545532 | ServoCity | https://www.servocity.com/channel-connector-plate-a | 2 | 30 | 15 | $3.99 | $59.85 | Mechanical Integration, Wheel Assembly
Pattern F Bracket | S7 | 585592 | ServoCity | https://www.servocity.com/flat-bracket-f | 1 | 8 | 8 | $2.89 | $23.12 | Rocker-Bogie
Single Pattern Bracket | S8 | 585468 | ServoCity | https://www.servocity.com/flat-single-channel-bracket | 1 | 1 | 1 | $1.49 | $1.49 | Differential Pivot
Motor Mount | S9 |  | ServoCity | https://www.servocity.com/hd-premium-planetary-gear-motor-mount-face-tapped | 1 | 4 | 4 | $4.99 | $19.96 | Corner Steering
#6 Washer | W1 | 92141A008 | McMaster | https://www.mcmaster.com/92141A008 | 100 | 28 | 1 | $1.17 | $1.17 | Rocker-Bogie
#4 Washer | W2 | 92141A005 | McMaster | https://www.mcmaster.com/92141A005 | 100 | 24 | 1 | $1.40 | $1.40 | Differential Pivot
0.5" Washers | W3 | 91545A280 | McMaster | https://www.mcmaster.com/91545A280 | 5 | 20 | 4 | $2.59 | $10.36 | Mechanical Integration, Rocker-Bogie
USB Xbox receiver |  |  | Amazon | https://www.amazon.com/Generic-Wireless-Gaming-Receiver-Xbox/dp/B01JC68MHU | 1 | 1 | 1 | $12.99 | $12.99
Xbox Controller |  |  | Amazon | https://www.amazon.com/FiveStar-Wireless-Controller-Microsoft-White/dp/B01LY6P5U4 | 1 | 1 | 1 | $25.99 | $25.99
#6 x 1/4 Spacer | T1 | 92510A442 | McMaster | https://www.mcmaster.com/92510A442 | 1 | 56 | 56 | $0.23 | $12.88 | Body, Corner Steering, Rocker-Bogie
#6-32 x 0.75" Standoff | T3 | 633126 | ServoCity | https://www.servocity.com/6-32-thread-1-4-od-round-aluminum-standoffs#371=256 | 4 | 8 | 2 | $1.89 | $3.78 | PCB Assembly, Wheel Assembly
#6-32 x 1.25" Standoff | T9 | 633134 | ServoCity | https://www.servocity.com/6-32-thread-1-4-od-round-aluminum-standoffs | 4 | 16 | 4 | $3.39 | $13.56 | Corner Steering
#4-40 x 1/4 Threaded Standoff | T4 | 91780A162 | McMaster | https://www.mcmaster.com/91780A162 | 1 | 1 | 1 | $0.23 | $0.23
#4-40 x 1/2 Threaded Standoff | T5 | 91780A164 | McMaster | https://www.mcmaster.com/91780A164 | 1 | 20 | 20 | $0.32 | $6.40
#4-40 x 3/4 Threaded Standoff | T6 | 91780A166 | McMaster | https://www.mcmaster.com/91780A164 | 1 | 1 | 1 | $0.37 | $0.37
M2.5 x 12mm Standoff | T7 | 95947A007 | McMaster | https://www.mcmaster.com/95947A007 | 1 | 1 | 1 | $0.64 | $0.64
#2-56 x 3/8" Threaded Standoff | T8 | 93330A252 | McMaster | https://www.mcmaster.com/93330A252 | 1 | 4 | 4 | $1.00 | $4.00 | PCB Assembly
M2.5 x 10 mm Standoff | T10 | 95947A005 | McMaster | https://www.mcmaster.com/95947a005 | 1 | 8 | 8 | $0.59 | $4.72 | Head Assembly, PCB Assembly
#2-56 x 1/2" Standoff | T11 | 91780A032 | McMaster | https://www.mcmaster.com/91780a032 | 1 | 20 | 20 | $0.41 | $8.20 | PCB Assembly
#4-40 Heat Set Inserts | I1 | 93365A120 | McMaster | https://www.mcmaster.com/93365a120 | 100 | 8 | 1 | $10.82 | $10.82 | Head Assembly
#6-32 Heat Set Inserts | I2 | 93365A130 | McMaster | https://www.mcmaster.com/93365a130 | 100 | 4 | 1 | $12.92 | $12.92 | Body
Allen Key Set | D2 |  |  |  |  | 1 |  |  |  | Wheel Assembly, Rocker-Bogie, Corner Steering, Body, Mechanical Integration, Differential Pivot
Center punch or Starter drill bit | D7 |  |  |  |  | 1 |  |  |  | Wheel Assembly, Differential Pivot
Hand Drill or Drill Press | D3 |  |  |  |  | 1 |  |  |  | Wheel Assembly, Differential Pivot
Drill bit \#23 | D6 |  |  |  |  | 1 |  |  |  | Wheel Assembly, Differential Pivot
Metal Hacksaw or Bandsaw | D4 |  |  |  |  | 1 |  |  |  | Rocker-Bogie, Head Assembly, Wheel Assembly, Differential Pivot
Vice clamp or C Clamps | D5 |  |  |  |  | 1 |  |  |  | Wheel Assembly, Differential Pivot
5/16 Wrench | D1 |  |  |  |  | 1 |  |  |  | Rocker-Bogie, Mechanical Integration, Wheel Assembly, Differential Pivot
Vice or V-Clamp | D8 |  |  |  |  | 1 |  |  |  | Head Assembly, Differential Pivot
YellowJacket 223 rpm drive motor | E49 | 5202-0002-0027 | GoBilda | https://www.gobilda.com/5202-series-yellow-jacket-planetary-gear-motor-26-9-1-ratio-223-rpm-3-3-5v-encoder/ | 1 | 6 | 6 | $39.99 | $239.94 | Wheel Assembly
M4 x 0.7mm 6mm screws | B15 | 2802-0004-0006 | GoBilda | https://www.gobilda.com/2802-series-zinc-plated-steel-button-head-screw-m4-x-0-7mm-6mm-length-25-pack/ | 25 | 48 | 2 | $1.79 | $3.58 | Wheel Assembly
GoBilda 2 hole U-Channel | S45 | 1120-0002-0072 | GoBilda | https://www.gobilda.com/1120-series-u-channel-2-hole-72mm-length/ | 1 | 6 | 6 | $2.79 | $33.48 | Wheel Assembly
GoBilda 23mm threaded plate | S46 | 2803-0023-0023 | GoBilda | https://www.gobilda.com/2803-series-stainless-steel-threaded-plate-23-23/ | 1 | 12 | 12 | $2.49 | $29.88 | Wheel Assembly
2-post 43-32mm drive motor clamping mount | S47 | 1401-0043-0032 | GoBilda | https://www.gobilda.com/1401-series-2-side-2-post-clamping-mount-43mm-width-32mm-bore/ | 1 | 6 | 6 | $5.99 | $35.94 | Wheel Assembly
GoBilda Pattern Adaptor | S48 | 1206-0016-0004 | GoBilda | https://www.gobilda.com/1206-series-pattern-adaptor-16-4/ | 1 | 12 | 12 | $4.99 | $59.88 | Wheel Assembly
6mm Bore Clamping D-Hub 0.770in | S49 | 545618 | ServoCity | https://www.servocity.com/6mm-bore-clamping-d-hub-tapped-0-770-pattern/ | 1 | 6 | 6 | $7.99 | $47.94 | Wheel Assembly
9 x 12 Bottom Plate | S51 |  | Sculpteo | https://www.sculpteo.com/ | 1 | 1 | 1 | $11.43 | $11.43 | Body

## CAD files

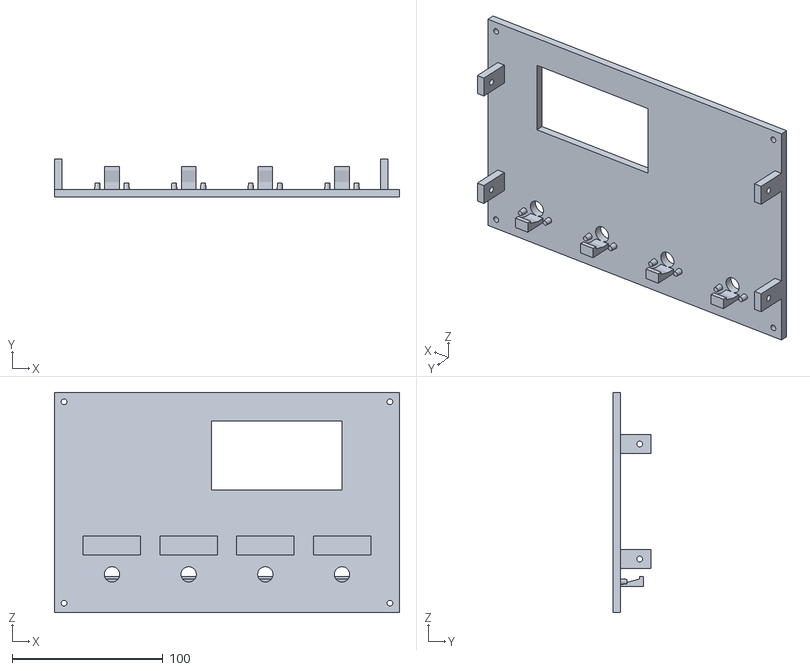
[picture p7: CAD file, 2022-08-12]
amp/BackPanel.STL
228.6 x 25.4 x 146.1

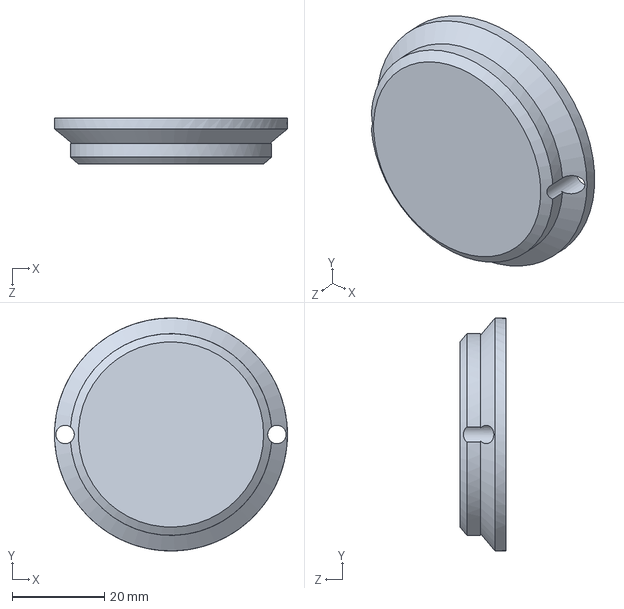
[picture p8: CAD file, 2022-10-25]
Motor_Cap.SLDPRT
50.6 x 50.6 x 10.0 mm

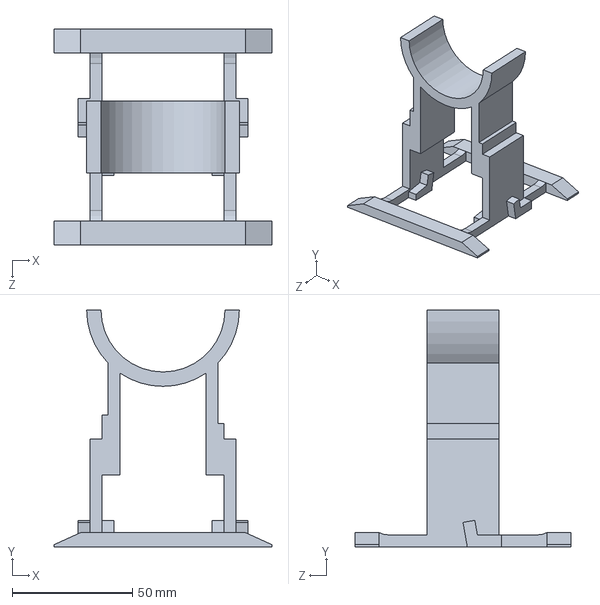
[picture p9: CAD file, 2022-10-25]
Mount Display Head.SLDPRT
90.6 x 98.7 x 90.0 mm

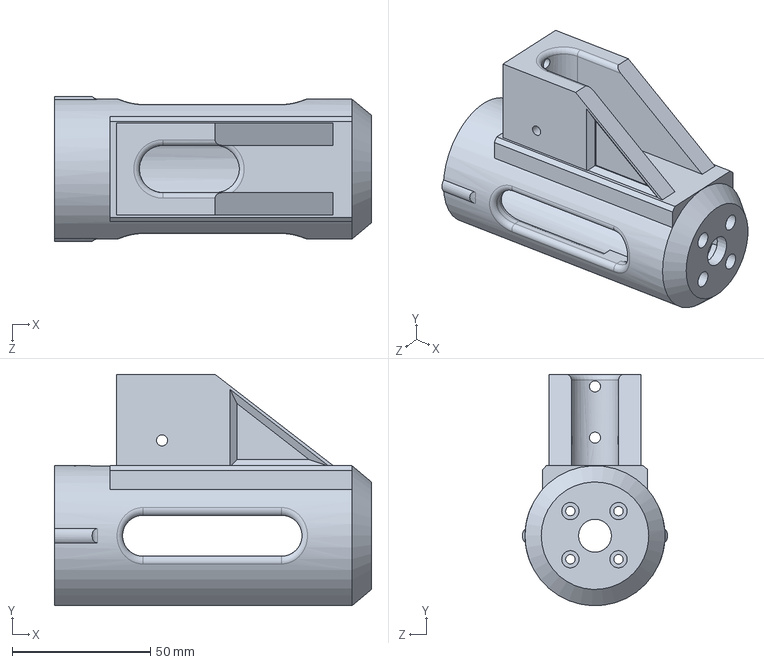
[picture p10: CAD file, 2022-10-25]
Motor Mountv2- VJ.SLDPRT
114.5 x 83.6 x 52.5 mm

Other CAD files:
Motor Mountv2- VJ.3MF
Motor_Cap.3MF
Mount Display Head.3MF

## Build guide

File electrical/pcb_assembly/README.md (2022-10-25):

# PCB Assembly



This document goes through the process of assembling and testing the custom
Printed Circuit Boards for the project. One thing you might notice is the boards
have reference designators on them that do not match the reference designators
used in the parts lists. The board components mapping between these can be found
below:

## 1. Control Board References

| **Component** | **Parts list Ref** | **Schematic Ref** |
| --- | --- | --- |
| Terminal block 6 pos top entry | E4 | J1-5 |
| Terminal block 6 pos side entry | E3 | J17-26 |
| Term block 2p side entry (5.08mm) | E12 | J13,15,16 |
| Connector Header pin 40P 40x1 | E15 | J8,9,11 |
| Connector Header pin 6P 6x1 | E14 | J10 |
| Connector Header socket 5P 5x1 | E6 | RC1-5 |
| Connector Header socket 40P 2x20  | E13 | J6,7 |
| Connector Header socket 20 2x10 | E5 | RC1-5 |
| Capacitor 100nF | E11 | C1-17 |
| Resistor 4.7K 1/4 Watt | E7 | R1 |
| Resistor 10K 1/4 Watt | E8 | R4,6,8,10 |
| Resistor 22K 1/4 Watt | E9 | R3,5,7,9 |
| Resistor 10K 1/2 Watt | E10 | R2 |
| LM358 Op Amp | E25 | U1,2 |
| DIP IC socket 8 Pos | E33 | U1,2 |
| Power Diode | E17 | D1 |
| 10A Fuse | E16 | F1 |
| USB A Connector | E34 | J12,14 |

## 2. Arduino Board References

| **Component** | **Parts list Ref** | **Schematic Ref** |
| --- | --- | --- |
| Term block 2P side entry | E16 | J6 |
| Connector Header pin 40P 40x1 | E15 | J2,3,4 |
| Connector Header 16P 2x8 | E30 | J1 |
| Connector Header 6P 6x1 | E14 | J5 |

## 3. Control Board Assembly

### 3.1 Motor & RoboClaw Connectors

| **Item** | **Ref** | **Qty** | **Image** | **Item** | **Ref** | **Qty** | **Image** |
| --- | --- | --- | ---| --- | --- | --- | ---|
| OSR Control Board | E1 | 1 |  |  10 Pos Header Socket  | E5 | 5 |  |
| 6 Pos Side Term Block | E3 | 10 |  |  5 Pos Header Socket | E6 | 5 |  |
| 6 Pos Top Term Block  | E4 | 5 |  |  Soldering Iron | N/A | | |

#### 3.1.1 Solder terminal blocks on top of board

Begin by soldering the 6 Position Side entry terminal blocks **E3** into the
   **top** side of the PCB, on the edge of the board as shown in the images
   below. These terminal blocks will run motor power, encoder power, and encoder
   signals between the motors/encoders and the RoboClaw motor controllers. The 6
   terminal blocks will each be labeled with schematic reference designators
   J17-J26 on the PCB. Be sure that the wire terminals face **OUTWARD** (away
   from the center of the board) on all of these connectors.

|   |
|:-:|
| Figure 1: Assembly Step 1 |

#### 3.1.2 Solder terminal blocks on bottom of board

On the **bottom** of the board, solder the 6 Position top entry terminal
   blocks **E4**. They will be labeled with schematic reference designators
   J1-5. The orientation of the wire terminal face should be AWAY from the each
   of RoboClaw outlines (see images below). These terminals will run battery
   power and +/- motor signals to the RoboClaw motor controllers from the PCB.

|   |
|:-:|
| Figure 1: Assembly Step 2 |

#### 3.1.3 Solder socket header connectors on bottom of board

On the **bottom** of the board, solder the 20-position female socket header
   connector **E5** and the 5-position female socket header connector **E6**.
   They will be labeled with reference designators RoboClaw 1-5. These are the
   digital signal pins for the RoboClaw motor controllers.

|   |
|:-:|
| Figure 1: Assembly Step 3 |

### 3.2 Resistors and Capacitors

| **Item** | **Ref** | **Qty** | **Image** | **Item** | **Ref** | **Qty** | **Image** |
| --- | --- | --- | --- | --- | --- | --- | --- |
| OSR Control Board | E1 | 1 |   | 22K 1/4 Watt Resistor  | E9 | 4 |   |
| 4.7K 1/4 Watt Resistor | E7 | 1 |   | 10K 1/2 Watt Resistor  | E10 | 1 |  |
| 10K 1/4 Watt Resistor  | E8 | 4 |   | 100nF Capacitor | E11 | 17 |  |

#### 3.2.1 Solder resistors and capacitors

On the **top** of the board, solder the resistors and capacitors by
    comparing the reference designator on the board to the part number listed in
    the table below. Some of these capacitors are used to store energy for
    powering components (to help protect against voltage fluctuations). Others
    are used as noise filtering mechanisms on analog signals (particularly to
    smooth the encoder signals). The resistors are needed to control the voltage
    across various components.

| **Item** | **Parts List Ref** | **Schematic/Board Ref** |
| --- | --- | --- |
| 4.7K 1/4 Watt Resistor | E7 | R1 |
| 10K 1/4 Watt Resistor  | E8 | R4,R6,R8,R10 |
| 22K 1/4 Watt Resistor  | E9 | R3, R5, R7, R9 |
| 10K 1/2 Watt Resistor  | E10 | R2 |
| 100nF Capacitor | E11 | C1-17 |

| |
|:-:|
| Figure 4: Resistor and Capacitor soldering |

### 3.3 Voltage Regulator connectors

| **Item** | **Ref** | **Qty** | **Image** |
| --- | --- | --- | --- |
| OSR Control Board | E1 | 1 |  |
| 5 Pos Header Socket | E6 | 2 |  |

#### 3.3.1 Solder 5-position header sockets

On the **bottom** of the board, solder the 5-position female header sockets
    **E6**. The sockets will have schematic reference designators of J9 and J11.
    These connectors are what the 12V and 5V voltage regulators will slot into.

|   |
|:-:|
| Figure 5: Assembly Step 5 |

### 3.4 Power Connectors

| **Item** | **Ref** | **Qty** | **Image** |
| --- | --- | --- | --- |
| OSR Control Board | E1 | 1 |  |
| 2 Pos Side Terminal Block | E12 | 3 |   |
| 2 Position 2.5mm Terminal Block | E18 | 1 |   |

#### 3.4.1 Solder 2-position terminal blocks on top of board

On the **top** of the board, solder the 2-position side entry terminal
    blocks **E13**. These will have schematic reference designators J14-16.
    Ensure that the wire terminals on these components face **OUTWARDS**. Also
    on the **top** of the board, solder the remaining 2-position 2.5mm terminal
    block **E18** (schematic reference designator J12).

|   |
|:-:|
| Figure 6: Assembly Step 6 |

### 3.5 Op Amp DIP socket

| **Item** | **Ref** | **Qty** | **Image** |
| --- | --- | --- | --- |
| OSR Control Board | E1 | 1 |   |
| 8 Pin DIP Socket  | E33 | 2 |  |

#### 3.5.1 Solder 8-pin DIP sockets

On the **top** of the board, solder the 8 Pin DIP sockets **E33**. They will
    have schematic reference designators U1-2. Orientation of these sockets does
    not matter, but note that you WILL (later, in another document) need to plug
    in the Op-Amp chips themselves, and orientation of those chips is important
    when you eventually complete that step. Placing the notch toward the right
    as pictured (toward the resistors and capacitors) will align the socket's
    notch with the chip's.

|   |
|:-:|
| Figure 7: Assembly Step 7 |

### 3.6 RPi GPIO Connector and misc headers

| **Item** | **Ref** | **Qty** | **Image** | **Item** | **Ref** | **Qty** | **Image** |
| --- | --- | --- | --- | --- | --- | --- | --- |
| OSR Control Board | E1 | 1 |   | 6 Position JST Connector | E14 | 1 |  |
| 40 Pin Header Connector  | E13 | 2 |  | 40 Position Header Pins  | E15 | 1 |  |

#### 3.6.1 Solder 40-position headers

On the **top** of the board, solder the 40-position header connectors
    **E13**. The clocking notch on the headers should face **OUTWARD** as shown
    below. The schematic reference designators are J6 and J7.

|   |
|:-:|
| Figure 8: Assembly Step 8 |

#### 3.6.2 Solder 40-position headers (2)

Take the 40 pin header pins **E15** and break off a 6-pin segment. On the
    **top** of the board, solder the 6-pin segment into schematic reference
    designator J8. Then, solder the JST connector **E14** into the J10 schematic
    reference designator. The opening in the pins on the JST connector should
    face **INWARD** as shown below.

|   |
|:-:|
| Figure 9: Assembly Step 9 |

### 3.7 Fuse and Diode

| **Item** | **Ref** | **Qty** | **Image** |
| --- | --- | --- | --- |
| OSR Control Board | E1 | 1 |   |
| 10 Amp Fuse | E16 | 1 |  |
| Diode | E17 | 1 |  |

#### 3.7.1 Solder fuse and diode

Solder the fuse **E16** and diode **E17** onto the top of the board into
    schematic reference designators F1 (fuse) and D1 (diode). **Pay careful
    attention to the direction that the Diode is mounted on the board**, as it
    will only work in one direction!

|   |
|:-:|
| Figure 10: Fuse and Diode Soldering |

### 3.8 USB connectors

| **Item** | **Ref** | **Qty** | **Image** |
| --- | --- | --- | --- |
| OSR Control Board | E1 | 1 |   |
| USB Connector | E34 | 1 |  |

#### 3.8.1 Solder USB connectors

On the **top** of the board, solder the two USB Connectors **E34**. They
    will have reference designators J12 and J14.

|   |
|:-:|
| Figure 10: Assembly Step 10 |

### 3.9 Standoffs

| **Item** | **Ref** | **Qty** | **Image** | **Item** | **Ref** | **Qty** | **Image** |
| --- | --- | --- | --- | --- | --- | --- | --- |
| #6-32 x 3/4" Threaded Standoff | T3 | 4 |     | #6-32 3/8" Button Head Screw | B2 | 8 |    |
| #4-40 x 1/2" Threaded Standoff | T5 | 20 |    | #4-40 1/4" Button Head Screw | B8 | 40 |    |
| #2-56 x 1/2" Threaded Standoff | T11 | 4 |     | #2-56 1/4" Button Head Screw | B13 | 8 |    |
| M2.5 x 10mm Threaded Standoff  | T10 | 4 |  | M2.5 x 6mm Socket Head Screw | B10 | 8 |  |

#### 3.9.1 Board mounting Standoffs

On the **BOTTOM** side of the board, attach
    the four #6-32 Standoffs **T3** on the outermost corner four mounting holes
    using screws **B2**. These standoffs will be used to attach the board to the
    robot chassis.

|   |
|:-:|
| Figure 12: Mounting Standoffs |

#### 3.9.2 RoboClaw mounting Standoffs

On the **BOTTOM** side of the board, attach
    the twenty #4-40 Standoffs **T5** using screws **B8** as shown below. You
    can identify the RoboClaw mounting holes as the ones that are inside the
    RoboClaw rectangles on the silk screen.

|  |
|:-:|
| Figure 13: RoboClaw Mounting Standoffs |

#### 3.9.3 Voltage Regulator Standoffs

On the **BOTTOM** side of the board, attach
    the four #2-56 Standoffs **T11** using screws **B13** as shown below.

|  |
|:-:|
| Figure 14: Voltage regulator Mounting Standoffs |

#### 3.9.4 Raspberry Pi Standoffs

On the **TOP** side of the board, attach the
    four M2.5 Standoffs **T10** using screws **B10** as shown in below.

|  |
|:-:|
| Figure 15: Raspberry Pi Standoffs |

|  |
|:-:|
| Figure 16: Standoffs Installed (Bottom View) |

## 4. Arduino Shield Assembly

| **Item** | **Ref** | **Qty** | **Image** | **Item** | **Ref** | **Qty** | **Image** |
| --- | --- | --- | --- | --- | --- | --- | --- |
| Arduino Shield | E2 | 1 |   | 1x6 JST header pins | E14 | 1 |  |
| 2 Position Term Block | E18 | 1 |  | 1x40 0.1 Pitch Header pins | E15 | 1 |  |
| 2x8 Shrouded Header Pins | E19 | 1 |  | Soldering Iron | N/A | | |

Now, we will assemble the Arduino shield that will sit in the rover's head and
control the face. We will start with the **TOP** side of the Arduino board. The
final product is shown below.

|   |
|:-:|
| Figure 17: Assembled Arduino Shield |

#### 4.1.1 Terminal Block assembly

Begin by taking the 2-position terminal block **E18** and soldering it to
    top of the board at the J6 connector, such that the screw terminals face
    outwards as shown below:

|  |
|:-:|
| Figure 18: Terminal Block assembly |

#### 4.1.2 JST assembly

Solder the 1x6 JST connector **E14** onto the top of the board at the J5
    connector such that the notch in the connector faces **OUTWARDS** as shown
    below:

|  |
|:-:|
| Figure 19: JST assembly |

#### 4.1.3 Terminal Block assembly

Solder the 2x8 shrouded header pin connector **E19** to the top of the board
    at connector J1 such that the notch faces **OUTWARDS** as shown in the final
    product image above.

|  |
|:-:|
| Figure 20: Terminal Block assembly |

#### 4.1.4 Pitch headers (1)

Solder the 0.1 pitch header pins **E15** to connectors J2-4 on the top side
    of the board:

|  |
|:-:|
| Figure 21: 0.1 Pitch headers (1) |

Flip the Arduino board over to the **BOTTOM** side where we will now install
    the remaining headers. The final product is shown in the images below.

#### 4.1.5 Pitch headers (2)

Solder the 0.1 pitch header pins **E15** to the bottom side of the board in
    the remaining hole sets.

|  |
|:-:|
| Figure 22: 0.1 Pitch headers (2) |

#### 4.1.6 Assembled

|   |
|:-:|
| Figure 23: Assembled Arduino Shield  |

# Component Integration and Testing

This next section will go over the process of integrating the electronics onto
the Control Board and the testing to verify that the board and components are
working as expected at each step. You should perform this section with the board
**outside** of the robot chassis in case you need to replace components or fix
any mistakes. It is important to do the following steps **one at time** so you
can verify that electronics are working as intended. These tests will save you
from accidentally breaking one or more of your components if something else is
plugged in incorrectly or shorted.

## 5. Testing the Control Board

### 5.1 Power Distribution System

| **Item** | **Ref** | **Qty** | **Image** | **Item** | **Ref** | **Qty** | **Image** |
| --- | --- | --- | --- | --- | --- | --- | --- |
| OSR Control Board | E1 | 1 |   | 5V Regulator | E22 | 1 |  |
| Battery | E36 | 1 |  | 12V Regulator | E23 | 1 |  |
| Tamiya Battery Connectors | E35 | 1 |  | RoboClaw Motor Controller | E20 | 5 |  |
| Red 20 AWG Wire | X1 | 1 |  | Op-Amp LM358P | E25 | 1 |  |
| Black 20 AWG Wire | X2 | 1 |  | Micro USB Cable | E28 | 1 |  |

#### 5.1.1 Test Step 1

Begin by powering the board. For testing purposes, we will plug the battery
    directly into the board, bypassing the switch and volt meter. Thus, the
    connection we use for testing will look a little bit different than when you
    fully install the board into the rover. Insert the red wire on the Tamiya
    Battery Connector **E35** into the IN terminal on connector **J16 / POWER
    SWITCH**, and the black wire to the GND terminal on the connector **J15 /
    BATTERY IN**.

|   |
|:-:|
| Figure 24: Test Step 1 |

#### 5.1.2 Test Step 2

Using a Digital Multimeter (DMM), probe the voltage across the test points
    T1 and T2. These will tell you the voltage at which the board power rails
    are, which should be the direct voltage of the battery. Verify that from T1
    to T2 reads a positive number, and is between 12V and 16.7V depending on the
    charge state of your battery.

|  |
|:-:|
| Figure 25: Test Pads |

#### 5.1.3 Test Step 3

| :exclamation: :exclamation: :exclamation: Battery Safety :exclamation: :exclamation: :exclamation: |
|:---------------------------|
| Unplug the Tamiya battery connector before plugging in or unplugging ANY components, or before inserting components!!!**(in future steps, we will not explicitly say to unplug the battery, but**you must disconnect the battery at each step BEFORE inserting components or working on the board!**).

Next, you will need to create jumper wires that will connect the RoboClaw motor controller power terminals to the RoboClaws. Take the red and black 24 AWG wires **W1 and W2** and cut 15 2-inch long segments of each color (you should have 15 red and 15 black pieces). Using wire strippers, strip the ends about 0.1 inches at each end. Insert these jumper wires into the terminal blocks on the RoboClaw Motor Controllers **E20** in the following way:

| **Terminal** | **Wire Color** |
| --- | --- |
| M1A | Red |
| M1B | Black |
| + | Red |
| - | Black |
| M2A | Red |
| M2B | Black |

#### 5.1.4 Test Step 4

Start by inserting one of the RoboClaws into the slot on the bottom of the
    board labeled `ROBOCLAW 2`. Connect the wires directly across from RoboClaw
    motor terminal block to the terminal block on the control board as shown
    below:

|   |
|:-:|
| Figure 26: RoboClaw power/motor wires |

#### 5.1.5 Test Step 5

Plug in the battery. An LED on the RoboClaw will turn on; verify that it is
    green. If the LED is red, it means there is an error. Error codes can be
    traced by looking at
    [the RoboClaw user manual](https://basicmicro.com/downloads).

#### 5.1.6 Test Step 6

Repeat this process one RoboClaw at a time **following the order of 2, 3, 4,
    1, 5** (testing each RoboClaw after you plug it in) until all 5 RoboClaws
    have been plugged into the board.

#### 5.1.7 Test Step 7

Take the two voltage regulators **E23 and 24** and solder their header pins
    to the bottom side of the board. Note that you will be soldering the short
    side of the pins on the top side of the board (the side with large
    capacitors on it).

#### 5.1.8 Test Step 8

Insert the 5V regulator into the control board as shown below. Power your
    board and probe between test points T4 and T2 on the top of the board below
    with your DMM and verify that it reads 5V. If it does not, make sure that
    the 5V regulator is slotted in properly and that your solder connections are
    solid.

|   |
|:-:|
| Figure 27: 5V Regulator & Test Pads |

#### 5.1.9 Test Step 9

Insert the 12V regulator into the control board. Power your board and probe
    between test point T5 and T6 on the top of the board with your DMM and
    verify that it reads 12V. If it does not, make sure the 12V regulator is
    slotted in properly and that your solder connections are solid.

|   |
|:-:|
| Figure 28: 12V Regulator & Test Pads |

If all voltage test points read expected values and all the RoboClaw motor
    Controllers have green LEDs, the power system has been verified!

## 6. Op-Amp Integration

Press the Op-Amp LM358P **E25** into the slots in the 8 Position DIP socket.
Take careful note of the direction of the chip in the DIP socket, as the notch
**MUST** face the correct direction.

|  |
|:-:|
| Figure 29: Op-Amp Integration |
![]()

### 6.1 Voltage Divider Verification

Now that the Op-amps are installed we want to check and make sure the voltage
dividers are working correctly. To do this, we will run power from the motors
directly back into the analog read signal, and see what voltage it gets divided
down to. On the motor connectors for each corner motor (J23-26), use a jumper
wire to connect the 5V signal line to the ENx line. Then, use a DMM to measure
the voltage between each of the following test pads and GND and compare the
values to the expected voltage ranges:

| Signal | Test Pad | Voltage (to ground, in Volts) |
| --- | --- | --- |
| Op Amp Power | T13 | 5 |
| M7 Encoder Signal Divided  | T7 | 1.5 – 2.0 |
| M7 Encoder Raw | T9 | 5 |
| M7 Encoder after Op-Amp | T11 | 1.5 – 2.0 |
| M8 Encoder Signal Divided  | T18 | 1.5 – 2.0 |
| M8 Encoder Raw | T20 | 5 |
| M8 Encoder after Op-Amp | T16 | 1.5 – 2.0 |
| M9 Encoder Signal Divided  | T8 | 1.5 – 2.0 |
| M9 Encoder Raw | T10 | 5 |
| M9 Encoder after Op-Amp | T12 | 1.5 – 2.0 |
| M10 Encoder Signal Divided | T19 | 1.5 – 2.0 |
| M10 Encoder Raw | T21 | 5 |
| M10 Encoder after Op-Amp | T17 | 1.5 – 2.0 |

### 6.2 RoboClaw Testing and Verification

In this section you will be going one by one and and testing the operation of
the RoboClaw Motor controllers. You will be doing this by using the GUI provided
by the manufacturer of the motor controllers. The GUI can be found at
[this link](https://www.basicmicro.com/downloads), under general downloads, then
BasicMicro Motion Studio.

You'll also need the `USB RoboClaw Windows Driver` from the RoboClaw General
Downloads section of the page. This should be installed before you run the
Motion Studio.

To use the GUI, insert a USB to Micro USB cable from your computer to the motor
controller you are going to be testing.

You must now make a temporary connection between the motor controllers and your
motors. We found it easiest to test using a set of male-male jumper wires
connected between the motor terminal being tested and a test motor.

### 6.3 Drive Motor Blocks

Do each of the steps below for the terminal blocks labeled J17-22; these
terminal blocks correspond to the driving motors for the rover. **Make sure that
while you are plugging in connections, your board is powered off!** The terminal
blocks correspond to the motor controller outputs in the following manner:

| Terminal Block Label | RoboClaw Board Label | Motor Output Channel |
| --- | --- | --- |
| J17 | RC1 | M1 |
| J18 | RC1 | M2 |
| J19 | RC2 | M1 |
| J20 | RC2 | M2 |
| J21 | RC3 | M1 |
| J22 | RC3 | M2 |

#### 6.3.1 Connect Wires

First, connect the wires in the following manner:

| Signal | Terminal Block Label | Motor Connector Wire Color |
| --- | --- | --- |
| Motor (+) | M+ | Red |
| Motor (-) | M- | Black |
| Ground | GND | Green |
| +5V | +5V | Blue |
| Encoder A | ENA | Yellow |
| Encoder | B | ENB White |

#### 6.3.2 Power on

Power on the board. After a minute or so, in the Basic Motion GUI you should
    see an available device appear. It might require an update to proceed;
    install the latest firmware update and then connect to the device.

#### 6.3.3 Prepare PWM signal

Click on the PWM tab. We will now send a PWM signal to the motor and test
    that connections are all made correctly to the motor and encoder.

#### 6.3.4 Vary PWM signal

Slowly move the slide bar for the corresponding motor output channel (Either
    M1 or M2 from the above table) for the terminal you are testing. Verify that
    the motor spins (we will worry about direction later), and that the encoder
    value is also changing (we'll worry about it increasing or decreasing
    correctly later as well). Switch direction of the slide bar and verify that
    it spins the other direction and the encoder value does the opposite of
    previous as well. If these are not happening or are backwards, go back and
    check that you are using the correct motor controller, terminal block, etc.
    If all your connections are correct, you may have to test your solder
    contact between the components on the board itself.

#### 6.3.5 Repeat for other motor terminals

Repeat the steps above for each of the drive motor terminal blocks, labeled
    J17-22.

### 6.4 Corner Motor Blocks

Do the following procedure for the terminal blocks labeled J23-26. These
correspond to the corner motors for the rover. Terminal blocks correspond to the
motor controller outputs in the following manner:

| Terminal Block Label | RoboClaw Board Label | Motor Output Channel |
| --- | --- | --- |
| J23 | RC4 | M1 |
| J24 | RC4 | M2 |
| J25 | RC5 | M1 |
| J26 | RC5 | M2 |

#### 6.4.1 Connect wires

Connect the wires to the motor in the following manner

| Signal | Terminal Block Label | Motor Connector Wire Color |
| --- | --- | --- |
| Motor (+) | M+ | Red |
| Motor (-) | M- | Black |

#### 6.4.2 Prepare encoder simulation

The main difference between the drive and corner motor systems is that for
    the corner system, we need to use the encoders. We want to test the voltage
    division circuit used on the control board; this divider which will expect
    a 0-5V signal from the absolute Hall effect encoder. To simulate the
    encoder, connect the +5V terminal on the motor terminal block straight into
    the ENA signal in the same terminal block.

#### 6.4.3 Connect to Basic Motion GUI

Connect to the motor controller in the Basic Motion GUI. Under the General
    settings tab (under Encoders), change the type of encoder from Quadrature to
    Absolute. You should see that the encoder values change to a number
    somewhere around 1600. As long as it is a fairly constant value and is in
    the range of 1400-2000 then everything is working. If the value varies
    wildly or is not in the 1400-2000 range, recheck that the OP-amp is
    installed in the correct direction. If this number still isn't correct then
    make sure you correctly installed all the resistors/capacitors in the
    assembly steps.

#### 6.4.4 Test PWM signal

Under the PWM tab, move the slide bar and verify that the motor spins
    accordingly.

#### 6.4.5 Repeat for other motors

Repeat this process for all the corner motor terminal blocks, labeled
    J23-26.

## 7. Raspberry Pi Install

Next up is to verify that power to the Raspberry Pi is working. For this, you'll
need a working operating system installed on the SD card. This will take some time; follow the
[software setup instructions](https://github.com/nasa-jpl/osr-rover-code#setup)
to install the rover software on the Raspberry Pi.

| **Item** | **Ref** | **Qty** | **Image** | **Item** | **Ref** | **Qty** | **Image** |
| --- | --- | --- | --- | --- | --- | --- | --- |
| OSR Control Board | E1 | 1 |  | 40 Pin Ribbon Cable | E29 | 1 |  |
| Raspberry Pi 3B | E21 | 1 |  | USB to Micro USB Cable | E27 | 1 |             |

| :exclamation: Only proceed with the following once you have successfully finished the installation of the rover code on your raspberry pi |
|:---------------------------|

#### 7.1.1 Attach RPi

Attach the Raspberry Pi to the board on top of the standoffs you attached
    earlier, making sure that the USB ports face downward on the board as shown
    below.

#### 7.1.2 Plug in cables

Plug in the micro USB cable **E27** to the USB power port labeled J12 and to
    the **power port** of the Raspberry Pi (labelled 'PWR'). Then, plug in the
    ribbon Cable **E29** into the Raspberry Pi GPIO header pins and connect the
    other end to the **J6** 40 pin GPIO connector.

|   |
|:-:|
| Figure 30: RPi Install |

## 8. Arduino Shield Testing

| **Item** | **Ref** | **Qty** | **Image** | **Item** | **Ref** | **Qty** | **Image** |
| --- | --- | --- | --- | --- | --- | --- | --- |
| Arduino Shield | E2 | 1 |   | 1x6 JST Cable | E26 | 1 |  |
| Arduino Uno | E24 | 1 |  | 16x32 LED Matrix | E37 | 1 |  |

Note: Testing the arduino board is dependent on finishing the control board and
having it tested fully. Do not proceed until you have successfully tested your
main control board.

Slot the Arduino Uno onto the bottom of the Arduino shield, matching the
footprints on the board.

|  |
|:-:|
| Figure 31: Arduino Shield Mounted |

#### 8.1.1 Plug in cable

Plug in the 1x6 JST cable **E26** into the Arduino shield and to the Control
    board. This cable will run 12V, 5V, GND, and two serial communication lines
    from the main rover to the Arduino shield which runs the screen in the head.
    This step relies on successful tests of the 5V and 12V regulators on the
    control board and verifying that they work correctly. If you have not tested
    the main board successfully, you may damage the Arduino.

#### 8.1.2 Measure

Using a Digital Multimeter, probe the following **Arduino shield test pads**
    and verify their voltages:

- TP1 to TP6 should read +12V. This voltage powers the Arduino Uno board

- TP5 to TP6 should read +5V. This voltage powers the LED Matrix and runs
        the LEDs on it

- TP4 to TP2 should read +5V. This is the 5V converter on the Arduino board

- TP3 to TP2 should read +3.3V. This is the 3.3V converter on the Arduino
        board

If all the above test points read the correct voltages, then the Arduino Shield
board is working correctly! You are now ready to finish the Electrical Assembly
of the rover!

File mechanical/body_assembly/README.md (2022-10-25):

# Main Body Assembly

The body is the housing of all the electronics for the rover. It is the attachment points for the rocker-bogie systems, as well as the differential pivot system.



## 1. Features

* Gives passthrough connections for USB ports on Raspberry Pi
* Cutouts on the rear of the body give access for voltage monitor and battery for charging
* Easy attachment point for differential pivot system
* Uses Actobotics parts to facilitate modularity and ability to change, and add new components easily.

## 2. Information about module

| Author/Creator | JPL |
| --- | --- |
| Cost without 3D printer | 253.28 |
| Cost with 3D printer | 240.38 |
| Date Added | 4/11 |
| Group/Organization/School | JPL |
| Time to build | 3 hrs |

### 2.1 Skills

* Band Saw/Dremel

### 2.2 Tools

#### 2.2.1 Mandatory

* Band saw or Dremel
* Allen Key set
* Imperial Wrench Set
* Soldering Iron

#### 2.2.2 Optional

* Laser cutter

### 2.3 Dependencies on Other Modules

* None

### 2.4 Mechanical Interface/Attachments to Rover

* 0.5 Inch aluminum rod into bearing blocks on rocker-bogie arms
* 0.5 Inch aluminum rod into clamping hub on differential pivot

## 3. Machining/Fabrication

### 3.1 9x12 Aluminum Plate Drilling

**Note: ServoCity has discontinued the 12x9 aluminum plates. Designs for replacement plates are available in the *[laser\_cut\_parts](laser_cut_parts/)* directory. If you need to use the laser cut parts, read the information found in [laser cut parts/README.md](laser_cut_parts/README.md) and then skip to section 3.2 of this document. The laser cut replacements have the necessary holes.**

| Item | Ref | Qty | Image |
| :--- | :-- | :-- | :---: |
| 9"x12" Aluminum Plate | S35 | 1 |  |

First we need to drill a hole in one of the 9x12 Aluminum plates **S35** because we will need a hole of just over 0.5 in diameter for the differential pivot mount. There is already a small hole drilled in the location we want to use, but it needs to be widened substantially. Start with the drill #23 and drill the hole shown by Figure 1. Repeat this with drill sizes stepping up until you get to a drill of 0.5 in.

Take the 0.5 in hollow rod **S19** and make sure it spins freely in the hole you have created. If it does not, drill the hole slightly larger or sand/file the hole until the rod spins with no resistance (The 0.5 in hollow rod must spin *freely* while mounted inside the bearing blocks. See step 2.2 Differential pivot for example. It may help to follow step 2.2 in this document to test if you have enough clearance)

|   |
|:-:|
| Figure 1: Drilling the Aluminum Plate |

### 3.2 Laser Cut Parts

The front and back panel of the rover are designed to be made from laser cut acrylic, as to keep them modular to design different things to mount there as wanted. The 2D cutout files  are the .DXF files  and can be found on the github under Mechanical - Body Assembly - Laser Cut Parts

If you do not have access to a lases cutter there is an online service which you can order these from below: <https://www.sculpteo.com>

To get the above parts from Sculpteo, go to Laser cutting and then upload these files (with mm selected as units). Hit Next. Make sure scale is set to 100%, change the material to Acrylic, have thickness to 1/8 inch, and then select whatever color you wish.

## 4. Mechanical/Structural Assembly

**DISCLAIMER** All images were created using CAD that has #6-32 Socket head cap screws, but the parts list calls for button head screws. The button head screws are correct.

### 4.1 Chassis

| Item | Ref | Qty | Image | Item | Ref | Qty | Image |
| :--- | :-- | :-- | :---: | :--- | :-- | :-- | :---: |
| Dual Side mount A | S17 | 4 |  | #6-32x1/4" Button Head Screw | B1 | 16 |  |
| 4.5"x12" Aluminum Plate | S37 | 2 |  | #6-32x3/8" Button Head Screw | B2 | 4 |  |
| 3D-printed PVC Clamp | S50 | 1 |  | Allen Key Set | | |  |
| 9"x12" Aluminum Plate | S35A | 1 |  | 5/16" Wrench | | |   |
| #6-32x5/8" Button Head Screw | B4 | 6 |  |#6 Washer| W1| 2| |
| #6-32 Heat set insert | I2 | 6 | |

#### 4.1.1 Top panel

Take the modified 9x12 Aluminum plate **S35A** and attach the four Dual side mount A **S17** using screws **B1** at the locations shown below. Take care to match the orientation shown.

|  |
|:-:|
| Figure 2: Attaching side mounts to top panel |

#### 4.1.2 Attach the side panels

Attach the 4.5x12 plates **S37** to the dual side mounts using screws **B1**

|  |
|:-:|
| Figure 3: Attach the side panels |

#### 4.1.3 Assemble the PVC clamping hub

* Insert the #6-32 Heat Set Inserts **I2** into the 3D-printed clamping hub **S50** in the locations shown in Figure 6. The inserts on the side of the clamp should go in from the left side as shown in Figure 4.
* Using washers **W1**, insert screws **B4** into clamp part of the clamping hub and screw part of the way into the brass inserts. Inserting these screws now simplifies inserting the PVC pipe later.

|  |
|:-:|
| Figure 4: Assemble PVC Clamping Hub |

#### 4.1.4 Attach the PVC clamping hub

Attach clamping hub **S50** to the top plate of the body using screws **B1** Use the location shown in Figure 5.

|  |
|:-:|
| Figure 5: Attach the PVC clamp to top plate |

### 4.2 Differential Pivot Block

The differential pivot is used to transfer weight off of the wheel that is currently climbing to the other front wheel, allowing the rover to climb more easily. Additionally, it serves as a second contact point for the rover’s body such that it does not rotate freely about the cross rod.

| Item | Ref | Qty | Image | Item | Ref | Qty | Image |
| :--- | :-- | :-- | :---: | :--- | :-- | :-- | :---: |
| 0.5" Pillow Bearing Block  | S11 | 2 |  | #6-32x1" Button Head Screw | B6 | 4 |  |
| #6-32x1/4" Spacer | T1 | 8 |  | Allen Key Set | D2 | |  |
| #6-32 Hex nuts | B11 | 4 |  |

#### 4.2.1 Mount the pillow bearing blocks

Using spacers **T1**, screws **B6**, and hex nut **B11**, mount the pillow blocks **S11** to the top of the body over the hole in the aluminum plate that you drilled earlier as shown in Figure 6.

|  |
|:-:|
| Figure 6: Mounting the pillow bloc |

### 4.3 Control Board PCB

| Item | Ref | Qty | Image |
| :--- | :-- | :-- | :---: |
| Assembled Control Board PCB | E1 | 1 |  |
| #6-32x3/8" Button Head Screw | B2 | 4 |  |

You may want to skip this step until the PCB is completed and tested and insert the PCB later.

#### 4.3.1 Mount the PCB

Mount the PCB **E1** to the top of the chassis using screws **B2**. Note the position of the PCB below.

|  |
|:-:|
| Figure 7: Mounting the PCB |

|  |
|:-:|
| Figure 8: Mounting the PCB |

Note the screw positions in Figure 8. You might not be able to get the screw circled in light blue in
because of the PVC clamping hub. This is okay, install the other 3 circled in yellow.

### 4.4 Closing the body

| Item | Ref | Qty | Image | Item | Ref | Qty | Image |
| :--- | :-- | :-- | :---: | :--- | :-- | :-- | :---: |
| Dual Side Mount A | S17 | 12 |   | Laser Cut Back Panel | S40 | 1 |  |
| #6-32x1/4" Button Head Screw | B1 | 28 |  | Switch | E39 | 1 |  |
| 9"x12" Aluminum Plate | S35 | 1 |  | 3D printed Battery Holder | S41 | 2 |  |
| Volt Meter | E38 | 1 |  | #6-32 Heat set insert | I2 | 4 |  |
| Laser Cut Front Panel | S39 | 1 |  | | | |

#### 4.4.1 Attach the Dual Side Mounts

Mount Dual Side Mounts A **S17** using screws **B1** on the side plates in both the front and back.

|  |
|:-:|
| Figure 9: Dual Side Mount A locations |

#### 4.4.2 Attach dual side mounts (2)

Also attach Dual Side Mounts A **S17** using **B1** screws on the top plate, in the front and back

|  |
|:-:|
| Figure 10: Dual Side Mount A (cont) |

#### 4.4.3 Front and back panels

Using screws **B1** attach the front and back laser cut panels to the chassis.

|  |
|:-:|
| Figure 11: Front and Back Panels attached |

#### 4.4.4 Attach the switch and volt meter

Take the Volt Meter **E38** and the Switch **E39** and attach them to the back panel. Note that the switch goes in from the inside of the body, and the volt meter should snap press fit in from the outside.

|  |
|:-:|
| Figure 12: Volt Meter/Switch Installation |

#### 4.4.5 Attach the Battery Holder

Take the 3D printed Battery holder **S41** and using a solder Iron at 460 degrees F, push the #6-32 heat-set insert **I2** into the battery holder as shown below.

|  |
|:-:|
| Figure 13: Installing heat set inserts|

#### 4.4.6 Install the battery holders

Mount the Battery holders onto the body assembly using screws **B1** as shown in Figure 14.

|  |
|:-:|
| Figure 14: Battery holder installation |

#### 4.4.7 Build bottom plate assembly

Take the 9x12 Aluminum Plate **S35** and attach 6 dual side mount A **S17** along the edges as shown in Figure 15. Be sure to verify that the orientation of the dual side mounts **S17** matches the pictures.

|  |
|:-:|
| Figure 15: Building the Bottom Panel |

#### 4.4.8 Attach the bottom plate

Take the bottom plate assembly you constructed in the previous step and attach it to the chassis.

|  |
|:-:|
| Figure 16: Attaching the Bottom Panel |

The Body Assembly is now Complete!

|  |
|:-:|
| Figure 17: Completed Body Assembly |

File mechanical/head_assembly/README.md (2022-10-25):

# Head Assembly

The head assembly serves as the head and face of our rover. It houses a 16x32 fully programmable 7 color LED matrix which we use as a display. The head can be used to show different faces and give your robot a personality, or even to show status and metrics about your rover (power, controller connectivity, battery level, etc)!



## 1. Features

* 3D printed components allows easy assembly; the housing was designed to be modular and printed separately, then fit together.
* Fully programmable 7-color LED matrix
* Custom PCB handles the switching the digital signal level between the Raspberry Pi and the LED matrix

## 2. Information about module

| Author/Creator | JPL |
| --- | --- |
| Cost without 3D printer | 97.80 |
| Cost with 3D printer | 84.90 |
| Date Added | 4/11 |
| Group/Organization/School | JPL |
| Time to build | 2 hrs |

## 2.1 Skills

* Band Saw/Dremel
* Drill Press/Hand Drill

## 2.2 Tools

### 2.2.1 Mandatory

* Band saw or Dremel
* Drill press or Hand Drill
* Allen Key set
* Imperial Wrench Set
* Soldering Iron

### 2.2.2 Optional

## 2.3 Dependencies on Other Modules

* None

## 2.4 Mechanical Interface/Attachments to Rover

* None

## 3. 3D Printing

There are a few components that need to be 3D printed to make the head assembly. You can find the STL files necessary for these prints in the [mechanical/head_assembly/3d_printed_parts](3d_printed_parts) folder of the repository.

|  |
| :--: |
| Figure 1: 3D Printed Parts |

If you do not have a 3D printer there are a number of online 3D printing services available, an example of which can be found at:

* [MakeXYZ](https://www.makexyz.com/)

Print the "head base.STL" piece from the [3d Printed head](https://github.com/nasa-jpl/open-source-rover/blob/master/mechanical/head_assembly/3d_printed_parts/head%20base.STL)

## 4. Laser Cutting

There is an acrylic plate which mounts the arduino into the head, as well as a back plate for the panel of the head. The 2D cutout files are the .DXF files and can be found in the GitHub repository at [Laser cut parts](https://github.com/nasa-jpl/open-source-rover/tree/master/mechanical/head_assembly/laser_cut_files). If you do not have access to a laser cutting there is an online service in which you can order these from below:

* [Sculpteo](https://sculpteo.com)

To get the above parts from Sculpteo, go to Laser cutting and then upload the .DXF files (make sure you select mm as units!). Hit Next. Make sure scale is set to 100%, change the material to Acrylic, set thickness to 1/8 inch, and then select whatever color you wish.

## 5. Machining/Fabrication

| Item | Ref | Qty | Image |
| :--- | :-- | :-- | :---: |
| 1" PVC Pipe | S29 | 1 | |
| Metal Hacksaw or Bandsaw | D4 | 1  |   |
| Vice clamp or C clamps | D5 | 1 |  |

### 5.1 Cutting the PVC Pipe

  Take the PVC pipe S29 (this will be the ”neck” of the rover) and cut it down to 4.5 inches long.

## 6. Mechanical/Structural Assembly

| Item | Ref | Qty | Image | Item | Ref | Qty | Image |
| :--- | :-- | :-- | :---: | :--- | :-- | :-- | :---: |
| 3D-printed Clamping Hub for 1" PVC Pipe | S24 | 1 |  | #6-32 x 3/8" Button Head Screw | B2 | 4 | |
| PVC Pipe (Modified ) | S29A | 1 |  | #4-40x 1/4" Button Head Screw| B8 | 12 | |
| Laser Cut Head Back Panel | S42 | 1 |  | M2.5 x 6mm Socket Head Screw | B10 | 8| |
| 3D printed Head | S43 | 1 |  | M3 x 6mm Socket Head Cap screw| B14 | 6 |  |
| Laser Cut Arduino Plate | S44 | 1 |  | Arduino Shield PCB |E2 | 1 |  |
| #4-40 Heat set insert | I1 | 8 |  | #6-32 Heat set insert | I2 | 6 | |
| Arduino Uno| E24 | 1 |  | #6-32 x 5/8" Button Head Screw | B4| 2 | |
| M2.5 x 10mm Standoff| T10 | 4 |  | LED Matrix | E37 | 1  |   |
|#6 Washer| W1| 2| |||||

## 6.1 Assemble the Arduino Stack

Begin by stacking together the Arduino Uno **E24**, Arduino Shield **E2**, Standoffs **T10**, Screws **B10**, and Arduino Plate **S44** and fastening them as shown in figure 2 & figure 3.

|  | |
|:-:|:-:|
| Figure 2 | Figure 3 |

## 6.2 Inserting the Heat set inserts

### 6.2.1 3D-printed head

Insert the # 4-40 Heat Set Inserts **I1** into the 3D printed head (using a Solder Iron at 460 degrees F) in the locations shown in Figures 4 and 5. For more information on using heat set inserts, see:

* [Heat set insert tutorial](https://www.lulzbot.com/learn/tutorials/heat-set-inserts-tips-and-tricks)

|  | |
|:-:|:-:|
| Figure 4 | Figure 5 |

|  | |
|:-:|:-:|
| Figure 6 | Figure 7 |

### 6.2.2 3D-printed PVC clamping hub

* Insert the #6-32 Heat Set Inserts **I2** into the 3D-printed clamping hub **S24** in the locations shown in Figure 8. The inserts on the side of the clamp should go in from the left side as shown in Figure 8.

|  |
| :------------------------------------------------: |
|                      Figure 8                      |

## 6.3 Assemble and Mount the PVC clamping hub

### 6.3.1

Using washers **W1**, insert screws **B4** into clamp part of the clamping hub and screw part of the way into the brass inserts. Inserting these screws now simplifies inserting the pipe later.

|  |
| :------------------------------------------------: |
|                      Figure 9                      |

### 6.3.2

Using screws **B2**, attach the completed PVC clamping hub to the bottom of the 3D printed head.

|  | |
|:-:|:-:|
| Figure 10 | Figure 11 |

## 6.4 Attach PVC Pipe

Slot the PVC pipe **S29** into the clamping hub and then tighten down the screws on the clamping hub

|  |
|:-:|
| Figure 12 |

## 6.5 Attaching the LED Matrix

Attach the LED Matrix **E37** to the front of the head assembly using Screws **B14**.

|  | |
|:-:|:-:|
| Figure 13 | Figure 14 |

## 6.6 Mount the Arduino Stack

Take the Arduino Plate assembly and mount it using screws **B8** to the heat set inserts on the posts inside the head as shown in Figure 15

|  | |
|:-:|:-:|
| Figure 15 | Figure 16 |

## 6.7 Back Plate Attachment

Attach the Laser Cut Back Plate **S42** onto the back of the head assembly using screws **B2**.

|  | |
|:-:|:-:|
| Figure 17 | Figure 18 |

The head is now finished!

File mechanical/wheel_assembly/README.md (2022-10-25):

# Wheel Assembly

The wheel assembly attaches the wheels to the motors and mounts the motors to the rest of the rocker-bogie suspension system that makes up the robot chassis.

Wheels picture
Final result.

## 1. Features

* The flexible wheels allow for high traction as they deform around objects, improving climbing performance
* Drive motors chosen to handle the high torque that the system sees, achieving both speed and climbing performance

## 2. Information about module

### 2.1 Skills

* Drill Press/Hand drill

### 2.2 Tools

* Drill Press or hand drill
* Allen Key set
* Imperial Wrench Set
* Optional: 3D printer

### 2.3 Dependencies on Other Modules

None

### 2.4 Mechanical Interface/Attachments to Rover

* Corner wheels: 1/4 clamping hub to 1/4 inch stainless steel shaft on corner steering
* Actobotics + GoBilda channels and channel connectors to rocker-bogie

## 3. Machining/Fabrication

| item | ref | qty | img |
| --- | --- | --- | ---: |
| wheels | S30 | 6 |  |
| hand drill or drill press | D3  | |  |
| center punch or starter drill bit | D7  | |  |
| drill bit #23 | D6  | |  |

Drill holes in the wheels as shown in Figure 1 using the center drill and drill \#23.

> The wheel is normally meant to be mounted using one bolt through the middle of the rim. This will not work well in our case as the rover sees very high torque at the wheel and the one-bolt system would be difficult to attach to any part of our system without the wheel slipping. To attach more firmly, we will drill two holes on either side of the original hole where we will mount the motor hub clamp as shown in Figure 1

|   |
|:-:|
| Figure 1: Drilling the wheels |

The important dimension is that the two holes are as close to 0.770 inches apart as possible while remaining centered about the center of the wheel. We found that the geometry shown in Figure 1 allowed us to get the holes most easily. Normally for these through holes you would use drill \#25, but in order to give a little extra tolerance we recommend a few steps up from that, something around drill \#23. Test the holes with the 4mm Clamping Hub **S14** to make sure the holes align as shown in Figure 1. If the holes do not align, you can file them out slightly or even attempt to re-drill them depending on how close you are. Repeat this drilling process for all 6 of the wheels.

## 4. Assembly

### 4.1 Assembling the base wheel mounts

Next, we will build the wheel assemblies which are divided into the middle wheels and corner wheel assemblies. We will build 6 identical base wheels and then add slightly more complexity onto 4 of those which will eventually become the corner wheels.

| item | ref  | qty | img | | item | ref | qty | img |
| --- | ---- | --- | --- | --- | --- | --- | --- | --- |
| channel | S45  | 6 | <image src="../../images/components/structural/S45.png" width="100"> | | drive motor | E49 | 6 | <image src="../../images/components/electronics/E49.png" width="100"> |
| 6mm D-hub | S49  | 6 | <image src="../../images/components/structural/S49.png" width="100"> | | M4 screws | B15 | 48  | <image src="../../images/components/screws/B15.png" width="100"> |
| clamping mount | S47  | 6 | <image src="../../images/components/structural/S47.png" width="100"> | | allen key set | D2  | | <image src="../../images/components/tools/D2.png" width="100"> |
| threaded plate | S46  | | <image src="../../images/components/structural/S46.png" width="100"> | | pattern adaptor | S48 | 4 | <image src="../../images/components/structural/S48.png" width="100"> |

#### 4.1.1 Prepare the motor channel

We will start by attaching pattern adaptors to connect the Servocity brackets to the bigger GoBilda brackets. Connect the pattern adaptor **S48** to the threaded plate **S46** using the screws that came with the pattern adaptor, as shown in Figure 2, but don't tighten the screws yet to make the next step easier. Now use M4 screws **B15** to attach the threaded plates **S46** to the GoBilda motor channel **S45**. The threaded plate should be on the outside of the channel. Once all screws are in, tighten them and make sure there is no air gap between the parts. Now repeat the process on the other side of the U-channel.

| <image src="../../images/wheels/step_1a.png" height="150"> <image src="../../images/wheels/step_1b.png" height="150"> <image src="../../images/wheels/step_1c.png" height="150"> <image src="../../images/wheels/step_1d.png" height="150"> |
|:-:|
| Figure 2: Connecting the pattern adaptors. The tolerances might be tight, in which case it's best to connect the M4 screw to the threaded plate where the hole is elongated first, then loosely insert the larger screw into the channel adaptor before you attach the remaining two screws.

#### 4.1.2 Motor mount

Attach the motor into the GoBilda channel **S45** you just prepared using clamping mount **S47** and screws **B15** as shown in Figure 3. Don't tighten the clamping mount to the motor all the way so we can adjust the positioning later to make the wheel center align with the corner steering axis. Slide on the motor shaft D-hub all the way back and tighten the clamp screw.

<image src="../../images/wheels/step_2.png" height="250">

Figure 3: Attaching the motor to the lower bracket

With that the base wheel assembly is completed! We will attach the wheels after building the corner wheel assemblies. Repeat above steps for the remaining 5 wheels.

### 4.2 Assembling the corner mounts

Now, we need to create the four corner wheels. These build on what we made for the base wheel assemblies in the last step. For the corner motors, we will need to extend the attachment point upwards as it is important that the axes of the corner steering motors are directly above the middle of the wheels to enable smooth steering.

| item | ref  | qty | img | | item | ref | qty | img |
| --- | ---- | --- | ---  | --- | --- | --- | --- | ---  |
| 3" channel | S2 | 4 | <image src="../../images/components/structural/S2.png" width="120"> | | 48 Tooth Plain Bore Gear | S26 | 4 | <image src="../../images/components/structural/S26.png" width="120">  |
| 4.5" channel | S4 | 4 | <image src="../../images/components/structural/S4.png" width="120"> | | 6-32 x 1/2" Button Head Screw | B3  | 8 | <image src="../../images/components/screws/B3.png" width="120"> |
| Channel connector plate | S6 | 12  | <image src="../../images/components/structural/S6.png" width="120"> | | 6-32 x 1/4" screws | B1  | 40  | <image src="../../images/components/screws/B1.png" width="120"> |
| 0.25" Face tapped clamping hub | S12  | 4 | <image src="../../images/components/structural/S12.png" width="120">  | | allen key set | D2  | | <image src="../../images/components/tools/D2.png" width="120"> |
| Loctite Threadlocker | S34  | | <image src="../../images/components/structural/S34.png" width="120">  | | 6-32 x 3/4" Threaded Standoff | T3  | 4 | <image src="../../images/components/standoffs/T3.png" width="120"> |
| wheels | S30A | 6 | <image src="../../images/components/structural/S30.png" width="120">  | | 6-32 x 5/8" screws | B4  | 12  | <image src="../../images/components/screws/B4.png" width="120"> |

#### 4.2.1 Channel Attachments 1

Attach 3 inch channel **S2** to your base wheel assembly using 8 screws **B1** as shown in Figure 4.

| <image src="../../images/wheels/attach_3in_channel_isometric.png" height="250"> <image src="../../images/wheels/attach_3in_channel_inside.png" height="250"> |
|:-:|
| Figure 4: Attaching the 3in channel to the motor assembly. |

#### 4.2.2 Preparing the 4.5 inch Channels - D-Clamping Hub Attachment

Attach the 0.25in clamping hub **S12** and the plane bore gear **S26** to the channel using screws **B3** from the top and **B1** from the bottom as shown in Figure 5.

|   |
|:-:|
| Figure 5: Attaching the large encoder gear |

#### 4.2.3 Preparing the 4.5 inch Channels - Hard stop mount

In order to keep the wheels from spinning too far in either direction, we will install a physical hard stop in the system. Attach a standoff **T3** with screw **B1** and optionally Loctite Threadlocker **S34** to the channel as shown in Figure 6. This standoff will be our hard stop. Make sure that you use the correct mounting hole or the standoff will not line up with the hard stops on the encoder mount.

| <image src="../../images/wheels/step_4.png" height="250"> |
|:-:|
| Figure 6: Attaching the hard stop that prevents the corner motor from rotating too far |

#### 4.2.4 Attaching the 4.5 inch channel

Attach the 4.5in channel **S4** to the top of the 3in channel from the last step using two channel connectors **S6** and screws **B1** as shown in Figure 7.

|   |
|:-:|
| Figure 7: Attach the 4.5in channel you made in step 3 to the base wheel mount |

#### 4.2.5 Repeat for the other corner wheels

You should have 4 corner assemblies and 2 base wheel assemblies.

### 4.3 Mounting the wheels

For all 6 assemblies, use screws **B4** to mount the wheels to the shaft clamp on the motors.

| <image src="../../images/wheels/step_6.png" height="250"> |
|:-:|
| Figure 8: Attaching the wheels |

Congratulations, you finished another major assembly!

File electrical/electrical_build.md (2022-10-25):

title

# Open Source Rover: Electrical Assembly Instructions
<!--Authors: Michael Cox, Eric Junkins, Olivia Lofaro

Reference herein to any specific commercial product, process, or service by trade name, trademark, manufacturer, or otherwise, does not constitute or imply its endorsement by the United States Government or the Jet Propulsion Laboratory, California Institute of Technology.

Copyright 2018 California Institute of Technology. Government sponsorship acknowledged
-->
# 1. Overview

First, it is important to examine the components we will use in the rover and understand how both data and power travel through the system. Figure 1 shows how each of the electrical components and boards receives power, and Figure 2 shows how data are sent from each of the electrical systems and what communication protocol it uses.



**Figure 1. Electrical Power Overview**

One important thing to note from the above is that there are multiple different voltages in the system. There is the unregulated voltage coming from the battery, 5V regulated coming from the voltage regulator, and the 12V motor voltage which is sent from the motor controllers to the motors.



  **Figure 2. Electrical Data Overview**

For the data transmission, we use both 3.3V and 5V digital logic systems, analog signals (of varying max voltages), and serial communication between devices. Information on these protocols can be found at:

* [Serial Communications](https://en.wikipedia.org/wiki/Serial%20communication)
* [Analog vs. Digital](https://learn.sparkfun.com/tutorials/analog-vs-digital)

**Table 1. Electrical Components**

Part | Description
---- | -----------
Battery | Provides power to the system. Has an unregulated voltage range of around 11.5V - 16.75V depending on its charge level
Switch | Mechanical disconnect of the electrical power to the rest of the robot
Volt Meter | Monitors and displays information such as current draw, voltage level, and power consumption of the robot
Voltage Regulator | Takes in the unregulated battery voltage and outputs a steady regulated voltage for consumption by electronics.
Raspberry Pi 3 | Acts as the brains and processing power of the robot
Arduino Uno | Runs the LED Matrix
LED Matrix | Gives the robot a display and a personality
Motor Controllers | Sends voltage signals to the motors telling the motors the direction and speed at which to spin. Reads encoder data
Encoders | Monitors the position of the motor to give information about speed and position
Control Board PCB | Custom Printed Circuit Board to manage power and data transmission between electronics components.

## 1.1 Prerequisite: Circuit Board Assembly

**NOTE**: Before proceeding, you need to have completed the assembly of the custom PCB board and populated all the components. If you have not yet done so, build the Control Board now by following the [PCB assembly instructions](pcb_assembly/README.md).

## 1.2. Tools Necessary

**Table 2. Necessary Tools**

Part|Image |Part| Image
----|------|----|-----
Heat Shrink Gun | |Solder |
Digital Mutimeter | |Solder Wick |
Soldering Iron | |Power Supply (optional) |

This project assumes you have the tools shown in Table 2. These will all be used in the construction and testing/debugging of this project. Most of these can be purchased inexpensively though DigiKey, Amazon, or other retailers.

## 1.3. Component Descriptions

The following are brief descriptions and basic notes about some of the components we use in this project. For more detailed information on each component, consult the data sheet for that component.

### 1.3.1 Battery

The battery is used to power all the electrical components and the motors in our rover. The biggest driving factor for battery selection was safety of the battery chemistry while still being able to drive the current and voltage necessary for operation of all the electronics (we’ll go into these requirements more later). The recommended battery was chosen because of its Poly Switch and PCB protection. These limit the amount of current that can be pulled from the battery, as well as give protection against things like electrical shorts and overcharging/fully discharging the battery.

### 1.3.2. Voltage Regulators

As our battery outputs unregulated voltage based on its charge level, voltage regulators are added to give steady DC power to the electronic components. There is a 5V regulator that runs the raspberry pi and the LED matrix, and a 12V regulator that supplies power to the Arduino Uno.

### 1.3.3. Raspberry Pi 3

We selected the Raspberry Pi 3 Model B as the ”brain” of the rover. We chose the Pi because it allows users at many levels of programming knowledge to gain familiarity in basic programming concepts without a complicated learning curve. It is also widely used in the maker community, so modifications and additions on the base rover should be easy. The Pi 3 also comes with WiFi and bluetooth modules built into the board and we therefore don’t need additional dongles to communicate over WiFi or bluetooth. This retains all 4 USB ports for addons and modifications to the project.

### 1.3.4. Arduino Uno

An Arduino Uno runs the LED matrix. The matrix is controlled by a set of GPIO pins from the Arduino and is multiplexed such that these few pins can control all the LEDs. Arduino is designed for these kinds of applications where very high frequency switching of GPIO pins are necessary. The Uno is better suited for this than the RPi, and offloads some compute power so that the Pi has more capacity to run rover software.

### 1.3.5. Control Board PCB

The custom Printed Circuit Board is designed to help manage the power distribution and data signals for the rover. It takes in battery power, splits it up to each of the voltage regulators and motor controllers which in turn power each of the individual electronics on the robot. It also takes in encoders from the motors and distributes them to the motor controllers, and provides serial UART communication between the RPi and the Motor controllers as well as the Arduino Uno. The first version of the Open Source Rover required you to run each of these wires by hand; the custom Control Board does much of the routing for you.

### 1.3.6. LED Matrix

The LED Matrix is a 16x32 pixel display that is controlled by the Arduino Uno. The LED matrix is controllable via software and can be programmed to display anything you like.

### 1.3.7. Motors

Motors cause the actual movement of the robot. There are many types of motors; in this project we will be used brushed DC motors. More information on different types of motors and a link about how brushed DC motors work can be found at the following links:

* [Brushed DC Motors](https://en.wikipedia.org/wiki/Brushed%20DC%20electric%20motor)
* [Electric Motors](https://en.wikipedia.org/wiki/Electric%20motor)

### 1.3.8. Encoders

Encoders give us readings on the position and speed of motors as they spin. There are two types of encoders in this project: absolute and quadrature. An absolute encoder is used to get the position of the motor on a fixed scale such that you always know the absolute position of the motor even after power cycling the system. Absolute encoders will usually have one output, which will either be a PWM digital signal or an analog signal. Each of these signals will have a specific reading corresponding to where the motor currently is on the fixed position scale. Absolute encoders are typically more expensive than their quadrature encoder counterparts, which will sense position only relative to the last time the power was cycled or the signal was reset. Quadrature encoders use two digital signals and look at the difference between the signals to sense movement. More information about quadrature encoders can be found at:

* [Quadrature Encoder Basics](https://www.dynapar.com/Technology/Encoder_Basics/Quadrature_Encoder/)

In this project, we use absolute encoders on the corner wheels to get absolute measurements on where the corner wheels are turned/pointed. We use quadrature encoders at each of the driving wheels to get speed measurements.

# 2. Powering Components

This section will go through the process of powering each of the components from the battery. During this project you will need to cut, strip, and solder wires to extend and split electrical connections. It is important to understand how to do this safely so that you are protecting your system from electrical shorts. Below are a few quick links on these skills, however it is crucial that you fully understand these processes before proceeding.

* [SparkFun Stripping Wire](https://learn.sparkfun.com/tutorials/working-with-wire/how-to-strip-a-wire)
* [Splicing Wire](https://www.wikihow.com/Splice-Wire)
* [YouTube Making Connections and Heat Shrink Tubing](https://www.youtube.com/watch?v=Y8wjv6lj5KU)

**Note: Please read through this entire section and understand it fully before starting to connect devices and electronics together.**

## 2.1. Switch, Volt Meter, and Control Board

| :exclamation: :exclamation: :exclamation: Battery Safety :exclamation: :exclamation: :exclamation: |
|:---------------------------|
| There are a couple of very important things to be aware of as you are making these connections, as with any project where you are working with batteries or electrical current: |
| **THE BATTERY IS LIVE AT ALL TIMES.** This means that at any point, if the two terminals of the battery come in contact they will cause an electrical short which could be very dangerous. This may trigger the protection circuit in the battery that we chose and prevent extensive damage, but we do not want to rely on that for safety. Make sure to keep the battery terminals of the +V and GND separated at all times with no possibility of contact. |
| The battery connectors will only fit together one way. That means you have to make sure your connections are correct the first time when soldering them in: make sure to verify this before connecting anything to the battery. |
| The switch we use is a Single Pole - Single Throw switch. This means that either the two terminals are connected together in one switch position or there is a physical disconnect when the switch is in the other position. Make sure to test the switch and know which are its **ON** and **OFF** positions previous to connecting it to anything. An easy way to test the switch is to use the ’Diode’ setting on your Digital Multimeter (DMM). |
| It is extremely important to plug the battery in the correct direction into the volt meter as well, as plugging it in backwards (even for an instant) could damage or destroy the volt meter.  |
| :exclamation: :exclamation: :exclamation: Battery Safety :exclamation: :exclamation: :exclamation: |

Using the Tamiya connectors, connect the battery to the switch and then the volt meter according to Figure 4. The Tamiya connectors allow you to disconnect the battery from the rest of the system so you can recharge the battery.

**Table 3. Necessary Parts**

Item | Ref | Qty | Image |Item | Ref | Qty | Image |
---- | --- | --- | ----- |---- | --- | --- | ----- |
Battery | E36 | 1 |  |Tamiya Connectors| E35 | 1 | 
16 AWG Wire (Black) | X2 | 1 |  |16 AWG Wire (Red) | X1 | 1 |  
Battery Charger | E41 | 1 | 

Battery and board connections

**Figure 4. Connecting the Battery to switch and board**

## 2.2. Powering the LED Screen

**Table 4. Necessary Parts**
Item | Ref | Qty | Image |Item | Ref | Qty | Image |
---- | --- | --- | ----- |---- | --- | --- | ----- |
LED Screen/Assembled Head | NA | 1 |  |4 Pin Molex Connector | E50 | 1 | 

Using The 4 Pin molex Cable that comes with the LED matrix, connect the LED matrix to the 5V output from the Arduino PCB mounted inside the Head assembly.

Powering the LED Screen

# 3. Connecting Data Cables

Next, we will next plug in all the cables that allow the various devices to communicate with each other.

**Table 5. Necessary Parts**

Item | Ref | Qty | Image |Item | Ref | Qty | Image
---- | --- | --- | ----- |---- | --- | --- | -----
Rectangular 6P 1x6 Jumper Cable | E26 | 1 | | USB Power Cable | E28 | 1| 
Rectangular 40P 2x20 Ribbon Cable | E29 | 1 | | Rectangular 16P Ribbon Cable | E30 | 1| 
 USB to TTL Serial Adapter | E48 | 1| 

1. Connect the **E26** cable from the J10 Connector on the Control Board to the J5 Connector on the Arduino Shield
1. Connect the **E30** 16 Position ribbon cable from the J1 Connector to the INPUT Connector on the LED Matrix
1. Connect the **E48** TTL serial to USB cable from any USB port on the Raspberry Pi to the 6 Position headers at J8. The pinout should match the table below (see Figure 5):

**Table 6. J8 Pins and Wire Colors**

Control Board PCB J8 pin | TTL Serial cable wire color
------------------------ | ---------------------------
GND | Black
N/A | Not Connected
5V | Red
TxD | Green
RxD | White
N/A | Not Connected

USB-serial

  **Figure 5. USB / TTL Serial Cable Connection**
  
# 4. Connecting Motors and Encoders

Next, we will connect the motors and encoders to the RoboClaw motor controllers. For each of the 10 motors you will need to connect motor power as well as the encoders. This means that there will be close to 60 wires traveling between the motor controllers and the motors/encoders, so it is very important to try to keep your wires organized and bundled together well. Below is some information about strain relief and using wire braid in your electronics systems. See these links and Figures 6 and 7 for examples.

* [Techopedia Strain Relief](https://www.techopedia.com/definition/2301/strain-relief)
* [YouTube Wire Braid](https://www.youtube.com/watch?v=FeCs98TSsYQ)



**Figure 6. Motor Wire Routing**

An example of how we routed our wiring is shown by Figure 6. It is important to give strain relief in the cable as you are routing it through, as well as to give extra wiring for the locations that can move. In addition, Figure 7 shows how we routed the wires through the rocker-bogie, and then from the rocker-bogie into the main body. Try to pick locations that reduce strain on the wires as the robot legs move when you are routing wires into the body.



**Figure 7. Serial signal routing**

**Table 7. Necessary Parts**

Item | Ref | Qty | Image |Item | Ref | Qty | Image
---- | --- | --- | ----- |---- | --- | --- | -----
20AWG Wire (Black) | X2 | N/A |  | 20AWG Wire (Red) | X1 | N/A | 
24AWG Wire (White) | X3 | N/A |  | 24AWG Wire (Blue) | X4 | N/A | 
24AWG Wire (Yellow) | X5 | N/A |  | 24AWG Wire (Green) | X6 | N/A | 
3 Pin Micro Connector | E40 | 4 | | Wire Braid | E42 | N/A | 
Heat Shrink Tubing | E44 | 1 | 

The below table and figure shows an approximate amount of length of wire you will need to reach each of the motors, based on how we think is best to route the wiring through the suspension system. Cut these lengths and strip both ends of the wires.

**Table 8. Wire Lengths by Section**

Section | Wires Needed | Length [inches]
------- | ------------ | ---------------
A | 2x 20AWG & 4x 24AWG | 35
B | 2x 20AWG & 4x 24AWG | 28
C | 2x 20AWG & 4x 24AWG | 48
D | 2x 20AWG & 3x 24AWG | 20
E | 2x 20AWG & 3x 24AWG | 32

Wire Lengths

**Figure 8. Wire lengths**

## 4.1. Drive Motors

We will begin with the drive motors (the 6 motors that are directly connected to each drive wheel). Make sure to look at which RoboClaw corresponds to which motors that that RoboClaw controls. It is important that this ordering is preserved. Figure 9 shows the motor pinout for the motors for the drive system. You will be wiring each of these to the terminal blocks on the control board. One method of doing this is to cut off the 6 pin connector from the motor and solder directly to the wires there. Another way is to add your own connector if you wish to be able to change the motor out easier in the future.

Roboclaw Motor Assignments

**Figure 9: RoboClaw - Motor Assignments**

The terminal blocks that correspond to the drive motors are connectors J17-J22. You will see them labeled on the control board corresponding to which motor it should connect to1.
Each of the terminal blocks are identical for the drive motors; pay attention to the silkscreen to know which screw terminal to plug the wire into. The terminal block position on the board will correspond roughly with which motor it goes to on the robot, ie. the J17 connector is in the front-right of the
board when installed in the robot, and connects to the front-right drive wheel.

**Table 9. Drive Motor and Encoder Wiring**

Control Board Label | Motor Wire Color | Signal
------------------- | ---------------- | ------
Mx+ | Red | Motor+
Mx- | Black | Motor-
GND + | Green | Ground
5V | Blue | Encoder Power
ENxA | Yellow | Encoder signal A
ENxB | White | Encoder signal B

## 4.2. Corner Motors/Encoders

The big difference between the corner motors and drive motors is that the corners use absolute encoders. The absolute encoders are separate from the motor and so we have to do a little bit of work to get them to interface with the motor controllers. The corner motors only have the two connections to the physical motor: the (+) and (-) going to the top of the motor. However, you must also hook up the absolute encoder. When plugged into the encoder, the 3-pin Micro connector will have 3 wires coming out of it, shown in Figure 10.

*Make sure you are using a REV-E or newer board. There was an initial release of board files that had the silkscreen reversed from left-right for all motors (drive and corner). If you have a REV-D or earlier board, the silkscreen may have these labels backwards.*

Encoder connection

**Figure 10. 3-pin Micro connector**

Pin | Description | Color
--- | ----------- | -----
1 | +5V DC Power | Orange
2 | 0-5V Analog | Blue
3 | Ground | Brown

Similar to the drive motors, connect each of the corner motors and encoders to its corresponding terminal block (J23-26 on the control board). Below is the pinout for how to connect the encoders:

**Note:** **These are NOT the same color and pinout as the drive motors!**

**Table 10. Steering Motor and Encoder Wiring**

Control Board Label | Motor Wire Color | Signal
------------------- | ---------------- | ------
Mx+ | Red | Motor+
Mx- | Black | Motor-
GND | Brown | Ground
+5V | Orange | Encoder Power
ENx | Blue | 0-5V Analog Signal

With that, all of the electrical wiring on your rover has been completed! You can now move onto the calibration process!

* [Calibration](calibration.md)

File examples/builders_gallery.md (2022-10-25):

# Builders' gallery

OSRs in the wild and under construction! Please [add your rover](#Instructions-for-adding-your-build) and add updates and pictures here as it evolves.

## JPL Rover

| <image src="images/jpl_rover/rover_at_open_house_1.jpg" height="350"> <image src="images/jpl_rover/rover_at_open_house_2.jpg" height="350"> |
|:-:|
| <image src="images/jpl_rover/jpl_rover_1.jpg" height="350"> <image src="images/jpl_rover/dsub.jpg" height="350"> |
|:-:|

<details>
  <summary>Expand to learn more about this build!</summary>
  
* Constructed in 2017, upgraded many times since!
* JPL has used this rover for many different events, from JPL/Mars outreach events, taking it to schools, local robotics clubs, and even a few robotic conferences!
* Maintained by a few different JPL employees over the years
  
### modifications

* Annodization! Before assembly of this version we got the metal pieces annodized a mix of red/black
* Micro D-Sub connectors at each of the rocker-bogies, so that both can be taken off easily and rover can be transported much easier!
  * [micro d-sub male](https://www.digikey.com/en/products/detail/itt-cannon-llc/M83513-03-D04N/2432917)
  * [micro d-sub female](https://www.digikey.com/en/products/detail/itt-cannon-llc/MDM-25SH006B/10491746)
* JPL Beanie! :)
  
</details>

## Robert the Rover ([Achille](https://github.com/Achllle))

| <image src="images/robert/robert1.png" height="150"> <image src="images/robert/robert2.jpg" height="150"> |
|:-:|

<details>
  <summary>Expand to learn more about this build!</summary>
  
### background

* I started construction in December 2019. Robert took his first steps about 3 months later.
* I use the rover for fun,
* I help maintain the two repositories. I'm a robotics engineer by training and happy to help with anyone stuck or with ideas. The best way to reach me is via Slack.

### modifications

* **bigger battery**: Robert runs off of [this 9Ah LiPo battery](https://www.amazon.com/gp/product/B07YP73LMX/ref=ppx_yo_dt_b_search_asin_title?ie=UTF8&psc=1)
* **RC**: For outdoor roving, I use a long-range [transmitter](https://www.amazon.com/gp/product/B08CKWZWPR/ref=ppx_yo_dt_b_asin_title_o03_s00?ie=UTF8&psc=1) and [receiver](https://www.amazon.com/gp/product/B07ZK1R32H/ref=ppx_yo_dt_b_asin_title_o02_s00?ie=UTF8&psc=1) from Spektrum.
* **sensor stack**: I mounted a lidar on top of my rover to allow for 2D mapping, localization, and navigation. I also have mounted (variations of) two monocular cameras, an IMU, and depth cameras to it. Details in [my blog post](https://www.freedomrobotics.ai/blog/how-to-pick-navigation-sensors-for-autonomous-mobile-robot).
* **toy trailer**: I bought this [toy trailer](https://www.amazon.com/gp/product/B0002HZQGO/ref=ppx_yo_dt_b_search_asin_title?ie=UTF8&psc=1) so that Robert can carry a payload. I attached it to Robert using a repurposed wrench and a collar clamp. It's not very robust but [it does the trick](https://youtu.be/caqx-S-_gv8)!
* **handle**: I used a strong piece of rope and a small piece of PCV tubing (handle) to lift the rover off the ground so I could carry it up and down stairs.
  
### blogs

  1. [Deploying on Mars: NASA-JPL Open Source Rover](https://www.freedomrobotics.ai/blog/building-the-nasa-jpl-open-source-rover)
  2. [Deploying on Mars: How to Pick Sensors to Enable Navigation for Your Autonomous Mobile Robot (AMR)
](https://www.freedomrobotics.ai/blog/how-to-pick-navigation-sensors-for-autonomous-mobile-robot)
  3. [Deploying on Mars: Rock solid Odometry for Wheeled Robots
](https://www.freedomrobotics.ai/blog/tuning-odometry-for-wheeled-robots)
  4. [Deploying on Mars: Rock solid Odometry for Wheeled Robots](https://www.freedomrobotics.ai/blog/deploying-on-mars-mapping-localization)

</details>

## Paddy-Rover ([Kit](github.com/apollokit))

| <image src="images/paddy/paddy1.jpg" height="150"> <image src="images/paddy/paddy2.png" height="150"> |
|:-:|

<details>
  <summary>Expand to learn more about this build!</summary>

  * I built Paddy through the winter of 2019-2020. She was (kinda) a covid baby!
  * It's been a great learning experience building and maintaining Paddy.
  * I help maintain the two repositories!
  
</details>
  
## Sinuhe's rover

| <image src="images/sinuhe/sinuhe1.png" height="250"> [<image src="images/sinuhe/video_icon.png" height="250">](https://youtu.be/jEhQtxJgvEM) |
|:-:|
  
<details>
  <summary>Expand to learn more about this build!</summary>

  This project help us get through covid year 2020!
  
  | <image src="images/sinuhe/electrical1.png" height="250"> <image src="images/sinuhe/electrical2.png" height="250"> |
  |:-:|
  
</details>
  
## Alex' rover
  
https://user-images.githubusercontent.com/14060847/160306700-88ff7ab6-efe0-483a-8637-53a57874fb1f.mp4
  
## Roverto ([toebes](github.com/toebes))

| <image src="images/roverto/roverto.jpg" height="150"> <image src="images/roverto/roverto_climbing_wheel.jpg" height="150"> |
|:-:|
<details>
 <summary>Expand to learn more about this build!</summary>

Built by the [Cardinal Gibbons Robotics](https://www.cghsnc.org/campuslife/co-curricular/robotics) team for use at outreach events.  Roverto has been to a few places, but is most at home on our [Mars Map courtesy of the Aldrin Foundation](https://aldrinfoundation.org/giant-mars-map/).  With it Roverto has been to:

* Astronomy days at the [North Carolina Museum of Natural Sciences](https://naturalsciences.org/) Three times.  One time Roverto had the opportunity to try and drive over a full size Curiosity wheel.  The last time we rand that event, there were over 14,000 attendees.
* [Galaxycon](https://galaxycon.com/pages/raleigh) Twice!
* The [North Carolina Transportation Museum](https://www.nctransportationmuseum.org/)
* Many events at [Cardinal Gibbons High School](https://www.cghsnc.org/).

### Enhancements

* The drive motors have been replaced by [Rev Robotics Core Hex Motors](https://www.revrobotics.com/rev-41-1300/) to give better torque
* The LED display has been updated with a [10" HDMI Touchscreen](https://www.sunfounder.com/products/10inch-touchscreen-for-raspberrypi).  We have a custom HTML web page which shows Roverto's face.
* Roverto has a custom development stand that lifts all the wheels off the ground for easy testing.

### Media
* [@robotics_cghsnc](https://twitter.com/robotics_cghsnc)

</details>

## USAi Labs AUDACITY ([JHPHELAN](github.com/JHPHELAN))

| <image src="images/AUDACITY/Houston-Robotics-Fidelity cropped.jpg" height="150"> <image src="images/AUDACITY/IMG_4751.JPG" height="150"> <image src="images/AUDACITY/IMG_3927.JPG" height="150"> <image src="images/AUDACITY/IMG_3931.JPG" height="150"> |
|:-:|
| AUDACITY 01 video (https://www.youtube.com/watch?v=n0Rx8EbABIY) |

<details>
  <summary>Expand to learn more about this build!</summary>
  
  ### Background
  * Started August 2019 as soon as we heard about the release of the NASA-JPL Open Source Rover
  * Named first version "Fidelity" to be as close to the NASA-JPL version as possible
  * Once initial parts had arrived, had a "part picking party" 
  * - with instructions from the manual for various sub-assemblies passed out, ziplock bagged & labeled
  * Sub-assemblies then assembled in groups
  * Had first roll-out almost exactly 1 year later after multiple delays, modifications, and frustrations as seen in .mp4 above
  
  ### Modifications
  * New version of rover named "AUDACITY" to be as boldly upgraded as possible to ultimately be autonomous
  * Raspberry Pi 3 >> Raspberry Pi 4b 4GB.  Perhaps later >> Jetson NANO to permit onboard AI "on the edge"
  * Raspbian >> Ubuntu 20.04
  * hand-coded Python >> ROS >> ROS2 Foxy
  * Upgraded PCB.  Looking forward to Rev F!
  * Upgraded drive & steering motors
  * Custom front/back acrylic panels
  * Emergency "Bop to Stop" switch.  Abandoned to free up room
  * Key fob remote power "Kill Switch" for range safety.  
  * - to substitue RoboClaw e-stop pins in future to stop motors but not CPU
  * Arduino driven LED "head" >> onboard LCD monitor - work in progress
  * Addition of cameras: Picamera, USB camera, Intel RealSense D450 Depthcamera, OAK-D Depthcamera |
  * - all works in progress and fraught with frustrations
  * Front bright LED "headlights" wired in parallel with drive motors.  Since polarity matters, only on when driving forward
  * Plan steering motors >> servos at some point

  ### External links
  1. [USAi Labs and Houston Community College  First rollout of rover](https://www.youtube.com/watch?v=2Wdgss0q63s)

</details>

## Instructions for adding your build

1. We'll be needing a little bit of git skills here. Although not strictly necessary, it helps to take a look at some tutorials on contributing using git & GitHub. Here are the basic steps.
   1. install git on your computer. On Linux, that means `sudo apt-get install git`
   2. Fork this repository by clicking the `Fork` button in the top right corner of the GitHub page.
   3. 'Clone' your fork to your computer by clicking the green `Code` button and copying the link. Type in `git clone` into your terminal and paste the link you just copied.
   4. Create a new branch and switch to it. `git checkout -b ourrovername_gallery`
   5. You're ready to start making changes! You can use any text editor of your liking, like [VS code](https://code.visualstudio.com/).
2. copy over someone else's section and adjust it to include your build's information. Add your entry to the bottom, just above this section. To keep this compact, add any text and details to the collapsible section (within the `<details> </details>` tags).
3. Create a new folder within [the images folder](./images) and add your rover's pictures to it.
4. Change the image links to point to your images. The format for that is `image src="images/your_folder_name/your_picture.jpg"`.
5. Commit your changes with git.
   1. in the terminal, navigate to this folder. `git status` should show that there are changes and new files.
   2. use `git add folder_name/file_name` for each change you want to include to stage those files.
   3. Commit these changes: `git commit -m "Adding my rover to the OSR gallery!"`
   4. Upload them using `git push origin ourrovername_gallery`, replacing `ourrovername_gallery` with the branch name you created earlier.
6. Create a Pull Request (PR) to suggest merging your code into the main branch.
   1. Navigate to the repository's [pull request page](https://github.com/nasa-jpl/open-source-rover/pulls) on GitHub. Click 'New pull request'.
   2. click 'compare across forks'.
   3. Select your fork from the head repository dropdown and pick your branch.
   4. click 'create pull request'. GitHub will take you to a page where you can create a title of your suggested changes and a description.
7. Wait for a maintainer to review your changes. They might ask you to make changes if something doesn't look right. Once the PR has been greenlighted, your changes will be added to the main branch!

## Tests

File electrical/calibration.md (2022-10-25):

<!-- Open Source Rover: Calibration
Authors: Michael Cox, Eric Junkins, Olivia Lofaro
Reference herein to any specific commercial product, process, or service by trade name, trademark, manufacturer, or otherwise, does not constitute or imply its endorsement by the United States Government or the Jet Propulsion Laboratory, California Institute of Technology. ⃝c 2018 California Institute of Technology. Government sponsorship acknowledged.
 1
-->


# Open Source Rover: RoboClaw Calibration

# 1. Calibration

In order for the motors to all work properly and drive the rover correctly, we must calibrate the motors and encoders. We will use a program called Basic Micro Studio to assist with this. BasicMicro Motion Studio can be downloaded at

* [Motion Studio Download](http://www.basicmicro.com/downloads)

We will now go through and check the encoders and motors one at a time and perform the calibration process on each of them. First, make sure that either the robot is fully hanging such that every drive wheel is not in contact with the ground, or that you elevate each drive wheel as you attempt to spin that wheel.

## 1.1 RoboClaw Setup

1.1.1 Connect your computer (with Basic Micro Studio installed) to the RoboClaw via USB- micro USB cable

1.1.2 Open Basic Micro Studio

1.1.3 If prompted, update the RoboClaw Firmware


 **Figure 1: Ion Studio Firmware Update**

1.1.4 Click the ’Connect Selected Unit’ box in the upper left

1.1.5 Verify that all the motor control parameters are roughly nominal:

* Temperature1: 30
* M1/M2 Amps: 0.00
* M1/M2 Encoder: 0
* M1/M2 Speed: 0
* Main Battery: Between 11.5-16.7V
* Logic Battery: 5V
* Model: 2x7a


**Figure 2**

As you perform the calibration and testing outlined in this document, make sure to monitor the values above and make sure they are changing in the way that you expect they should. For instance, the temperature going much higher than 35 would indicate that something is going wrong, or if you are pulling a large amount of current you might have a short in the wiring.

1.1.6 Under the General Settings Tab, you’ll need to change the following settings for each RoboClaw:


**Figure 3**

(a) Setup:

* Control Mode: Packet Serial
  * Multi-Unit: Check Enable Multi-Unit Mode

(b) Serial:

* Set the address to 128,129,130,131,132 for each respective RoboClaw
* (Robo- Claw 1 is address 128, 2 is address 129, etc)
* Baudrate: 115200

(c) Battery:

* Max Main Battery: 17.5V
* Min Main Battery: 11.5V

(d) Motors:

* We will be updating the motor current parameters after calibration is complete.

(e) I/O:

* Encoder 1 Mode: Quadrature for addresses 128,129,130; Absolute for addresses 131 and 132
* Encoder 2 Mode: Quadrature for addresses 128,129,130; Absolute for addresses 131 and 132

**1.1.7 After changing these settings, make sure to save them! (Device − > Write Settings )**

## 1.2 Drive Motor Calibration

1.2.1 Perform the following steps for the **RoboClaw addresses 128,129, and 130**:

* Go to the PWM settings tab


 **Figure 4**

(a) Under the control pane, slowly move the slider bar up for Motor1.


**Figure 5**

(b) Verify that when the forward signal is sent to the motor (the Motor1 slider is above 0), the wheel spins in the direction that would move the rover as a whole forward (note this is different clockwise vs counterclockwise based on which wheel you are testing). **If the wheel moves backwards with respect to the rover direction, then under the General Settings tab click the checkbox labeled ’Reverse M Relative Direction based on which motor is wrong.**

(c) Now as you drive M1 motor forward (which now corresponds to the rover moving forward), verify that M1 Encoder value increases. **If the encoder value decreases go to the General tab and under I/O click the Invert checkbox for the Encoder Mode.**

(d) Repeat steps 1.2.1 b) and 1.2.1 c) for M2 motor.

1.2.2 Once both motors are spinning the correct direction and the encoders respond accordingly when commanded through the PWM Signal tab, move on to the Velocity Settings tab.


**Figure 6**

Here we’ll be tuning the motor settings. We need to do this in order to have fluid control of the motor, and it needs to be done for each individual motor as they will all differ slightly out of the box. Therefore, each motor must be be individually tuned. For more information on motor PID controls and what they do you can visit:

* [An Introduction to PID Control with DC Motor](https://medium.com/pollenrobotics/an-introduction-to-pid-control-with-dc-motor-1fa3b26ec661)
* [The Working of a PID Controller](https://www.elprocus.com/the-working-of-a-pid-controller/)

There has been significant feedback that the BasicMicro Motion Studio auto tune sometimes does not work, and so we have included a section at the end of this document about how to tune the motors yourself.

(a) Begin by entering in the QPPS (quadrature pulses per second), or the maximum number of encoder ticks per second. To find this value, drive the motor at max speed in the PWM setting and look at the box labeled ’M1/M2 Speed’.


**Figure 7**

(b) Now hit the Tune M1 button. This will populate the Velocity P, I, and D variables on the M1 side. Repeat this step for M2 motor as well.


**Figure 8**

(c) Once both motors on this motor controller have been tuned go back to the General settings tab and update the Motor Parameters to have a Max current of 15.0 Amps. Then go to Device − > Save Settings and then exit. Repeat all of steps 6 through 8 for the other drive motors.
  
## 1.3 Corner Motor Calibration

1.3.1 Perform the following for the **RoboClaw addresses 131 and 132**:

(a) Perform step 6 above for the corner motors, making sure to set the encoder type to absolute.

(b) Go to the PWM Settings tab and **slowly** drive the M1 corner forward. Verify that the encoder value goes up. If it does not, switch the motor wire leads at M1A and M1B.2

(c) Repeat step 9b for M2 motor

(d) You may need to set the absolute encoder ”zero” point in a different location. In order to avoid ”clipping” of the range of the encoder, we’ll set the mid-point of the absolute encoder to be the middle of the turning arc.

* Navigate to the PWM Settings tab to move the corner to its ”center” position, which is where the wheel is directly forward.

* Unscrew the small gear at the bottom of the absolute encoder
  * Once the absolute encoder shaft is uncoupled from the robot, spin the encoder until you determine the max value. This should be somewhere in the range of 1400-18004.

* As opposed to the drive motors, the corners use absolute encoders that are defined in one direction only, so you cannot switch the direction of the encoder.

Clipping occurs when you go past the 360 deg mark on the encoder and it starts again at 0.

If you are getting encoder values of close to 2000 and the value stays above 2000 and does not reset to 0 while the shaft is spinning, it means that the voltage divider board is not working properly. Check to make sure the resistors on the voltage divider board are the correct values.

* Spin the encoder until it reads a value of roughly half its max value and reattach the gear, coupling it back to the rover.

(e) For each motor M1 and M2, we now need to obtain what is the new min and max encoder values. Using the PWM Settings tab, move the motors until they run into the physical hard stops. Record the min and max encoder values for each, but for the min values add at least 15 and the max subtract at least 155.

(f) Navigate to the Position Settings tab.


**Figure 9**

(g) Enter your Min and Max encoder values for each M1 and M2 motor. We add a buffer of at least 5 encoder ticks to avoid driving the motors all the way into the hard stop; In other words, we’ll impose a software ’soft stop’

  
     **Figure 10**

(h) Change the Autotune type to **PD** and then tune the M1 and M2 motors by clicking the ’Tune M1’ and ’Tune M2’ buttons. We’ve found that this autotuning process is more successful if you run it with the wheels down on a smooth surface, but still supporting the weight of the robot.


**Figure 11**

(i) To verify that the corner steering motors have been calibrated, move the M1 and M2 sliders to their middle positions (halfway between min and max) and verify that the wheels all point exactly straight forwards. If they do not point straight forwards, verify that your min and max values are correct and ensure that no signal clipping is happening on the encoders.

(j) After the motors have both been tuned go to General settings and set the Motor current Max to be 15.0 Amps for each motor.

(k) Repeat Step 9 for the remaining corner motors

## 2. Manual Calibration

This section is to preform a manual tuning and calibration of the Corner motor system. This will be using the Ziegler-Nichols tuning method. For a more in depth explanation of how this process works you can visit:

* [Tuning for PID Controllers](http://faculty.mercer.edu/jenkins_he/documents/TuningforPIDControllers.pdf)

These steps assume you have already set the max/min values of the encoders in the position tab, as well as verified the encoder direction. If you have not done those follow the steps in the Corner Calibration

1. Determine the QPPS of your system. This is the quadrature pulses per second at max speed of the motor. For that run your motor at max speed using the PWM settings tab, and look at the motor speed. This value just has to be initially close, so generally you can use the same number for all of the same motor types ie. Drive vs Corner motors.
2. In the GUI under the position settings tab have it graph the Motor(x) position, and Motor(x) setpoint, where(x) is the motor you are tuning.
3. Go to the Position Tab. Set all PID gains to be zero.
4. Enter in the QPPS from step 1.
5. Increase the P value and then use the position slider to command the setpoint of the motor. Initially I started my P value at 10 for the first increment. The motor should move to this position. If it stops immediately at the value then the system is over-damped. Keep increasing the P value until the motor beings to have a stead-state oscillation which doe NOT damp out to the setpoint. This value is called Kc. I found mine to be usually between 10-20 for values of P, which I incremented in steps of 0.5 at a time.
6. Now that the system is oscillating back and forth you have to get the period of the oscillation. Do this by starting a timer and timing how long it takes to do 30 oscillations. For mine it was around 10 seconds. Divide that time by the number of oscillations, this gives you the period, which is called Pcr. I found this to be generally around 0.3s
7. The approximate gains can be found using the following equations:
    <!-- Maybe convert the equations to graphics -->

    P = 0.6Kc  
    <!-- (1)-->

    I = 0.5Pcr
    <!-- (2) -->

    D = 0.125Pcr
    <!-- (3)-->
8. Enter in these values into the GUI and use the slid bar to set the setpoint and see the motor response on the graph. More than likely what will happen is it will overshoot and do one oscillation. This means that the P value is slightly too high. Decrease the P value in small steps until you see no overshoot of the setpoint in the graph. Once that happens your corner motors will be appropriately tuned.
